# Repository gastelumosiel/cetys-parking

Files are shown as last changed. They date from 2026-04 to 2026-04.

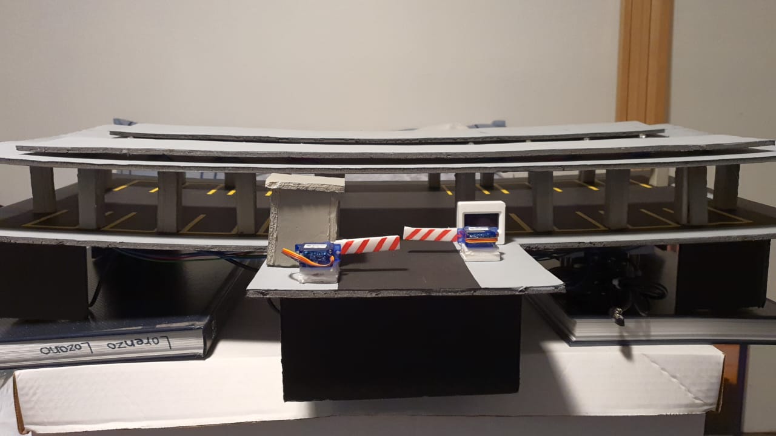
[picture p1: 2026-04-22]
media/model.jpg

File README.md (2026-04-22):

# cetys-parking
CETYSParking is an IoT-based smart parking system using STM32, sensors, and a web interface for real-time monitoring, reservations, and access control. The system uses MQTT and Node-RED for real-time communication, enabling scalable and efficient parking optimization through data-driven insights.

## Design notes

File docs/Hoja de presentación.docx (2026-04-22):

Fecha | 3 de diciembre de 2025
Nombre del proyecto | CetysParking
Integrantes del equipo | Osiel Gastélum Zazueta, 35596
| Rene Lozano García, 32827
Descripción breve del proyecto | Sistema automatizado de monitoreo de estacionamiento, compuesto por el uso de sensores en los cajones, así como en la entrada del mismo de acuerdo a disponibilidad; LEDs RGB muestran el estado individual de cada cajón (rojo ocupado, verde libre y ámbar reservado). Los usuarios cuentan con una interfaz web que permite visualizar las ocupaciones en tiempo real y la información correspondiente al historial reciente. Igualmente se permite realizar una reservación a la vez por usuario en caso de que se requiera con anticipación dicho espacio.
Objetivos alcanzables | No. | Objetivo | Resultado
| 1 | Detección de estacionamientos con el uso de sensores inductivos, así como la exposición de su estado a través de LEDs RGB.
| 2 | Control de pluma con Servo motor al detectar a un carro en la entrada. El acceso se permite o no dependiendo de la disponibilidad de cajones.
| 3 | Se monitorean los tiempos de acceso, ocupación de cajones y salida del estacionamiento con respecto al reloj real (Pacific Time).
| 4 | Reserva de espacios a través del interfaz web; se permite un cambio de LED específico a lo largo del tiempo de reserva definido.
| 5 | Interfaz visual remota que permite monitorear en tiempo real la disponibilidad de cajones, realizar reservaciones o revisar estadísticas relevantes de los mismos.
Expectativas individuales de cada integrante | Osiel G. | Se espera fundamentar el uso de distintos tipos de protocolos de comunicación a través de una sola arquitectura de microcontroladores, así como diseñar una solución tangible (interfaz web gráfico en este caso) para una problemática real. Al final, se busca que la conceptualización del proyecto combine el uso de sensores, actuadores e interfaces para ofrecer monitoreo en tiempo real de los estacionamientos en alguna institución educativa.
| Rene L. | Al trabajar en partes independientes, se ha probado la capacidad del MCU para interactuar y comunicar con diferentes interfaces, pero se espera en este proyecto integrar todas las diferentes funciones y que funcionen a buena capacidad sin que una no afecte a la otra. La placa de desarrollo NUCLEO144-F767ZI cuenta con todos los periféricos necesarios para hacer de este proyecto una realidad, y será una prueba de fuego para llevar este microcontrolador a sus límites.

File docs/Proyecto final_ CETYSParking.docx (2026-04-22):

CENTRO DE ENSEÑANZA TÉCNICA Y SUPERIOR

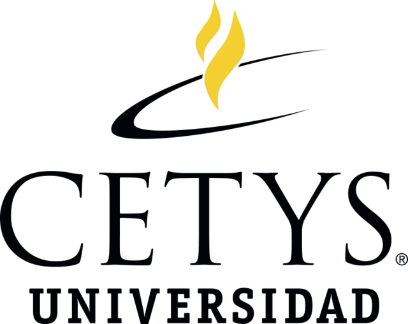
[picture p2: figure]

Escuela de ingeniería
Ingeniería en Cibernética Electrónica

Diseño de interfaces

Proyecto final:

CETYSParking

Presentan:

Osiel Gastélum Zazueta, 35596

Rene Lozano García, 32827

Tijuana, B.C., 3 de diciembre de 2025

# Índice general

1. Introducción 6

2. Planteamiento del problema 6

3. Justificación del problema 8

4. Objetivos 9

4.1 Objetivo general 9

4.2 Objetivos particulares 9

5. Desarrollo del proyecto 10

5.1 Arquitectura del sistema 10

5.1.1 Capa de hardware 10

5.1.2 Capa de Presentación 11

5.2 Implementación de Hardware 12

5.2.1 Microcontrolador STM32F767ZI 12

5.2.2 Distribución de pines GPIO 13

5.2.4 Sistema de Detección con Sensores Inductivos 15

5.2.5 Pantalla OLED SH1106 15

5.2.6 Control de Servomotor 16

5.3 Implementación de Software 16

5.3.1 Comunicación MQTT 16

5.3.2 Lógica de Detección y Cambio de Estado 17

5.4 Integración y Comunicaciones 17

5.4.1 Arquitectura Node-RED 17

5.5 Base de Datos y Almacenamiento 18

5.6 Interfaz de Usuario Web 19

5.6.1 Sistema de Autenticación 20

5.6.2 Vista de Estacionamientos: Monitoreo en Tiempo Real 21

5.6.2.1 Dashboard de Estadísticas Instantáneas 21

5.6.2.2 Grid Visual de Cajones 22

5.6.2.4 Interacción Hardware → Interfaz Web 23

5.6.2.5 Persistencia de estado 24

5.6.2.6 Vista de Reservas: Interacción Web → Hardware 24

5.6.2.6.1 Proceso de Reserva Paso a Paso 24

5.6.2.6.2 Gestión temporal automática 27

5.6.2.7 Vista de Estadísticas: Análisis y Predicción 27

5.6.2.8 Comunicación en tiempo real 29

6. Conclusiones y resultados finales 30

7. Referencias 33

8. Anexos 35

8.1 Anexo A: Fragmento relevante del main() en la STM32 35

# Índice de figuras

Figura 1: Arquitectura general del sistema CETYSParking 8

Figura 2: Configuración de pines en CubeMX 11

Figura 3: Diagrama de flujo Node-RED 16

Figura 4: Interfaz web de visualización de estacionamientos 18

Figura 5: Autenticación de inicio de sesión 19

Figura 6: Estadísticas instantáneas 20

Figura 7: Grid visual de estacionamientos con indicadores de color 21

Figura 8: Proceso de reserva, selección de lugar disponible 24

Figura 9: Elección de horario de llegada y salida 24

Figura 10: Confirmación de reserva y visualización de resumen 25

Figura 11: Visualización de estadísticas de disponibilidad y uso 27

# Índice de tablas

Tabla 1: Especificaciones técnicas del microcontrolador STM32F767ZI 11

Tabla 2: Distribución de pines para LEDs y sensores inductivos 12

Tabla 3: Estados de cajones y representación mediante colores 13

Tabla 4: Mensajes MQTT implementados en el sistema 16

Tabla 5: Estructura de la base de datos EntradasSalidas 17

# CETYSParking

# 1. Introducción

La gestión eficiente de estacionamientos representa uno de los desafíos más apremiantes en instituciones educativas modernas, donde el crecimiento exponencial de la matrícula estudiantil contrasta con la limitada expansión de la infraestructura vehicular. En el contexto de CETYS Universidad Tijuana, esta problemática se manifiesta en patrones de ocupación impredecibles que generan incertidumbre y pérdida de tiempo para la comunidad universitaria.

El presente proyecto propone el desarrollo de un sistema inteligente de gestión de estacionamientos que integra tecnologías IoT, sensores inductivos y microcontroladores STM32 para optimizar el uso de recursos existentes. A través de una arquitectura basada en detección vehicular en tiempo real y una interfaz web interactiva, el sistema permitirá monitorear la disponibilidad de espacios, gestionar reservas anticipadas y controlar el acceso automatizado mediante actuadores especializados.

La solución implementa una maqueta demostrativa que simula dos estacionamientos con ocho espacios totales, incorporando indicadores LED RGB para señalización visual, sensores inductivos para detección precisa de vehículos, y una pantalla OLED para retroalimentación local. El sistema utiliza Node-RED para la gestión de datos en tiempo real y comunicación MQTT para garantizar la sincronización entre componentes hardware y software.

Esta implementación representa un modelo escalable que puede adaptarse a diferentes contextos institucionales, contribuyendo al desarrollo de infraestructura inteligente y sostenible en el ámbito educativo.

# 2. Planteamiento del problema

La globalización y urbanización del mundo ha traído consigo problemas constantes problemas en zonas de ciudad debido a la naturaleza de crecimiento exponencial en población de las mismas. Aunque el tráfico de automóviles sugiere ser uno de los aspectos más controversiales, ciudades como la de Tijuana se enfrentan a la escasez de estacionamientos; existe un aumento considerable de espacios de estacionamiento, pero a su vez, un indiscriminado deseo de usarlos (Hurtado, 2022). En particular, instituciones educativas universitarias se ven afectadas por la irregularidad del número de vehículos registrados a nombre de cada alumno; resulta complicado tener un estimado real de la proporción de alumnos que cuentan con un auto, y, aunado al inevitable crecimiento de la población estudiantil, se evidencia la falta inminente de un cajón de estacionamiento para cada alumno.

La Universidad Autónoma de Baja California registró un crecimiento del 41.49% en su matrícula en Tijuana durante un período de cinco años, una tendencia que se replica en instituciones educativas de la región y que presiona significativamente la infraestructura de estacionamiento existente (Martínez, 2014). Los estándares internacionales recomiendan mantener una proporción de un lugar de estacionamiento por cada 10 estudiantes, sin embargo, la realidad operativa muestra deficiencias en el cumplimiento de esta ratio, especialmente durante horarios pico de clases (Parklio, 2023).

La problemática se intensifica en el campus de Cetys Universidad Tijuana, donde los dos estacionamientos principales experimentan patrones de ocupación impredecibles que generan incertidumbre tanto para estudiantes como para personal administrativo. La ausencia de un sistema de información que permita la gestión inteligente de los recursos existentes constituye la raíz del problema. Las instituciones carecen de herramientas digitales para el monitoreo en tiempo real, análisis de patrones de uso y comunicación proactiva con la comunidad universitaria sobre disponibilidad de espacios. Esta deficiencia tecnológica impide la optimización de los recursos actuales y dificulta la planificación estratégica para el crecimiento institucional proyectado.

La implementación de un sistema de gestión de estacionamientos representa una solución escalable que puede adaptarse al crecimiento de la matrícula estudiantil sin requerir inversiones proporcionales en infraestructura física. El sistema permitirá a los usuarios registrarse para tener acceso y monitorear el flujo vehicular en tiempo real, facilitando la toma de decisiones informadas antes de llegar al campus y optimizando la utilización de ambos estacionamientos disponibles.

# 3. Justificación del problema

Con la elaboración de este proyecto, se pretende utilizar el microcontrolador STM32 a su máxima capacidad, para sincronizar el control de los periféricos con el correcto funcionamiento. La operación de una página servirá como un gran reto para la implementación de la interfaz para observar el estado de la disponibilidad. Por otro lado, la implementación de los llamados Smart Parking ha demostrado beneficios significativos en diversas instituciones a nivel mundial, estableciendo ecosistemas de servicio especializados que mejoran la experiencia del usuario y la eficiencia operativa (Zimmermann et al., 2023).

La relevancia del proyecto radica en su contribución al desarrollo de ciudades inteligentes mediante la integración de soluciones tecnológicas verdes que fomentan la sustentabilidad ambiental. Los sistemas de información verde (Green IS) han emergido como herramientas fundamentales para abordar desafíos urbanos contemporáneos, donde la gestión eficiente del estacionamiento contribuye directamente a la reducción de emisiones vehiculares y optimización del tráfico urbano (Brauer et al., 2015).

Desde una perspectiva técnica, los avances en sistemas de estacionamiento basados en asignación de recursos y reservas han demostrado su efectividad en la reducción del tiempo de búsqueda y mejora de la satisfacción del usuario. Los sistemas modernos integran sensores IoT, microcontroladores especializados e interfaces web para crear soluciones escalables que pueden adaptarse a diferentes contextos institucionales. La utilización de microcontroladores STM32, sensores inductivos, actuadores LED RGB y sistemas de comunicación ethernet permitirá desarrollar una solución robusta que combine monitoreo en tiempo real con capacidades de reserva anticipada de espacios.

El impacto esperado del proyecto trasciende la solución inmediata del problema de estacionamiento, posicionándose como una inversión estratégica en infraestructura tecnológica que beneficiará a toda la comunidad universitaria. La reducción estimada de 10-15 minutos en tiempo de búsqueda por estudiante representa no solo mejoras en productividad académica, sino también contribuciones tangibles a la sustentabilidad ambiental mediante la disminución de emisiones vehiculares y consumo de combustible.

# 4. Objetivos

## 4.1 Objetivo general

El objetivo general es diseñar y construir un sistema, con apoyo de una maqueta demostrativa, que ejemplifica la operación y contraste los beneficios que supondría la implementación de dicha arquitectura que permite monitorear la disponibilidad de los estacionamientos en Cetys.

## 4.2 Objetivos particulares

1. Interfaz web. Comunicación en tiempo real con Node-RED para mostrar el número de espacios libres; diseño gráfico del estacionamiento, con el asfalto y líneas divisorias de espacios para facilitar la identificación de lugares.
2. Control de acceso. Control de pluma con Servo motor al detectar a un carro en la entrada. El acceso se permite o no dependiendo de la disponibilidad de cajones.
3. Indicador visual. Mediante una pantalla OLED, mostrar disponibilidad en la entrada, al lado del Servo motor.
4. Reserva de cajones. Reserva de espacios a través del interfaz web; se permite un cambio de LED específico a lo largo del tiempo de reserva definido.
5. Estacionamiento múltiple. Creación de dos espacios de estacionamiento distintos (dos en total, con ocho cajones cada uno) para permitir su aplicación en instituciones como Cetys Universidad.
6. Sincronización temporal. Se monitorean los tiempos de acceso, ocupación de cajones y salida del estacionamiento con respecto al reloj real (Pacific Time).

# 5. Desarrollo del proyecto

## 5.1 Arquitectura del sistema

El sistema CETYSParking implementa una arquitectura distribuida de tres capas que garantiza modularidad, escalabilidad y mantenibilidad del sistema completo.

###### Figura 1 Arquitectura general del sistema CETYSParking

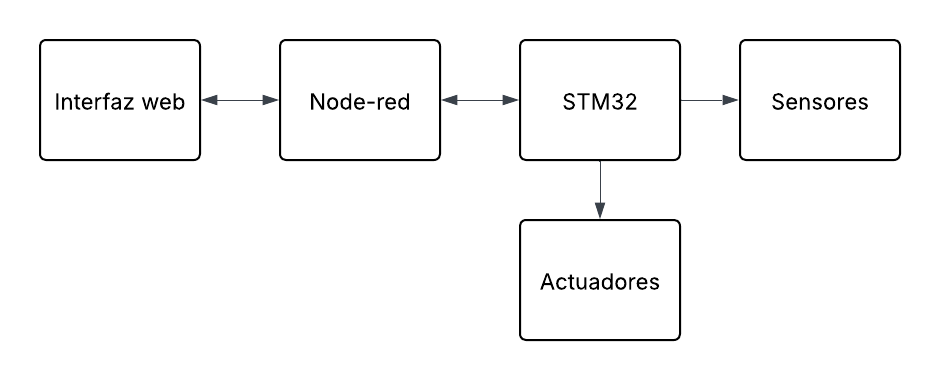
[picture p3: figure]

### 5.1.1 Capa de hardware

La capa física del sistema está compuesta por el microcontrolador STM32F767ZI Nucleo-144, que actúa como núcleo central de procesamiento. Este dispositivo fue seleccionado por sus capacidades de conectividad Ethernet RMII, su procesador ARM Cortex-M7 de 216 MHz, y su amplia disponibilidad de periféricos integrados.

Para la detección vehicular, se implementaron ocho sensores inductivos por estacionamiento conectados a pines GPIO configurados como entradas digitales con interrupciones externas (EXTI). Estos sensores proporcionan señales de bajo nivel (0V) cuando detectan la presencia de un vehículo metálico, y alto nivel (3.3V) cuando el espacio está libre.

La señalización visual se implementó mediante LEDs RGB distribuidos en tres arrays independientes por estacionamiento: LEDs verdes (estado libre), LEDs rojos (estado ocupado) y LEDs azules (estado reservado). Esta codificación por colores es consistente con estándares internacionales de señalización.

El control de acceso se implementa mediante un servomotor conectado al timer TIM1, configurado para generar señales PWM con frecuencia de 50 Hz. El servomotor simula una pluma de acceso que se levanta cuando hay cajones disponibles y permanece cerrada cuando el estacionamiento está lleno.

Para retroalimentación local, se integró una pantalla OLED SH1106 de 128x64 píxeles comunicada mediante protocolo SPI. Esta pantalla muestra en tiempo real el número de cajones disponibles, ocupados y reservados.

Capa de Procesamiento y Comunicaciones

El firmware del STM32 fue desarrollado utilizando STM32CubeIDE con la biblioteca HAL de STMicroelectronics. La arquitectura de software implementa un sistema de eventos basado en interrupciones y polling periódico para detección de cambios de estado.

La comunicación con la capa de presentación se implementó mediante MQTT sobre Ethernet, utilizando la biblioteca Mongoose Embedded Web Server Library integrada con mbedTLS para comunicación segura. El microcontrolador actúa como cliente MQTT conectándose a un broker HiveMQ Cloud en la nube, publicando mensajes en el topic "device1/tx" cada vez que ocurre un cambio de estado en algún cajón.

Node-RED actúa como orquestador central del sistema, suscribiéndose a los topics MQTT para recibir eventos desde el hardware, procesando los datos mediante nodos de transformación, almacenando información histórica en MySQL, y redistribuyendo eventos procesados hacia la interfaz web mediante uibuilder y hacia el microcontrolador mediante el topic "device1/rx".

### 5.1.2 Capa de Presentación

La interfaz web fue desarrollada utilizando Vue.js 3 con arquitectura reactiva, permitiendo actualizaciones instantáneas ante cambios de estado. La aplicación implementa tres vistas principales: visualización de estacionamientos, sistema de reservas, y panel de estadísticas con predicción basada en datos históricos.

La comunicación en tiempo real entre Node-RED y la interfaz web se implementó mediante Socket.IO a través del módulo uibuilder, garantizando latencia mínima en la actualización de estados visuales. El sistema de autenticación implementa un esquema con credenciales del usuario, con capacidad de extensión hacia sistemas institucionales.

## 5.2 Implementación de Hardware

### 5.2.1 Microcontrolador STM32F767ZI

El microcontrolador seleccionado es el STM32F767ZI montado en la placa Nucleo-144, proporcionando un entorno de desarrollo robusto y profesional.

###### Tabla 1. Especificaciones técnicas del microcontrolador STM32F767ZI

Característica | Especificación
Procesador | ARM Cortex-M7 @ 216 MHz
Memoria Flash | 2 MB
Memoria RAM | 512 KB
Conectividad | Ethernet 10/100 RMII
Perifericos | 4x SPI, 4x I2C, 8x USART
Timers | 2x 32-bit, 10x 16-bit
ADC | 3x 12-bit, 24 canales
GPIO | 168 pines I/O

La configuración del microcontrolador se realizó mediante STM32CubeMX, generando el código de inicialización para los siguientes periféricos clave: Ethernet (ETH) en modo RMII, SPI1 para comunicación con pantalla OLED, Timers (TIM1, TIM2, TIM9) para PWM y delays, RTC con cristal LSE para mantenimiento de tiempo preciso, RNG para generación de números aleatorios en conexiones TLS, y múltiples pines GPIO organizados funcionalmente.

### 5.2.2 Distribución de pines GPIO

###### Tabla 2. Distribución de pines para LEDs y sensores inductivos

Función | Cantidad | Configuración
LEDs Verdes (libre) | 8 por estacionamiento | Output Push-Pull, Pull down
LEDs Rojos (ocupado) | 8 por estacionamiento | Output Push-Pull, Pull down
LEDs Azules (reservado) | 8 por estacionamiento | Output Push-Pull, Pull down
Sensores inductivos | 4 por estacionamiento | Input, Pull-up, EXTI
Servomotor PWM | 2 en total | TIM1 Channel 1, 50 Hz
OLED SPI | 5 pines | SP1, CS, DC, RESET

###### Figura 2 Configuración de pines en CubeMX

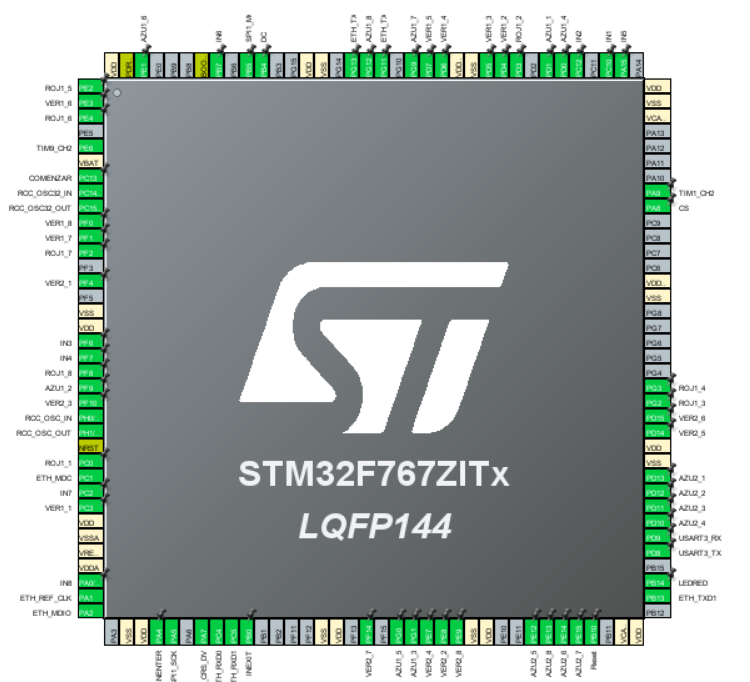
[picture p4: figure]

5.2.3 Sistema de LEDs RGB

Cada cajón de estacionamiento cuenta con un LED RGB de cátodo común, conectado a tres pines GPIO independientes (uno por color). El sistema implementa control mediante nivel lógico bajo para encendido (LEDON = 0) y nivel alto para apagado (LEDOFF = 1).

###### Tabla 3. Estados de cajones y representación mediante colores

Estado | Color LED | Valor constante | Significado
Libre | Verde | LIBRE = 0 | Cajón disponible
Ocupado | Rojo | OCUPADO = 1 | Cajón ocupado
Reservado | Azul | RESERVADO = 2 | Cajón reservado

La función de control de LEDs implementa una máquina de estados simple que apaga todos los colores primero y luego enciende el correspondiente al estado deseado:

void SetLEDState(int spotIndex, int state) {
// Apagar todos los colores
HAL_GPIO_WritePin(leds_verdes[spotIndex].port,
leds_verdes[spotIndex].pin, LEDOFF);
HAL_GPIO_WritePin(leds_rojos[spotIndex].port,
leds_rojos[spotIndex].pin, LEDOFF);
HAL_GPIO_WritePin(leds_azules[spotIndex].port,
leds_azules[spotIndex].pin, LEDOFF);
// Encender el color correspondiente
switch(state) {
case LIBRE:
HAL_GPIO_WritePin(leds_verdes[spotIndex].port,
leds_verdes[spotIndex].pin, LEDON);
break;
case OCUPADO:
HAL_GPIO_WritePin(leds_rojos[spotIndex].port,
leds_rojos[spotIndex].pin, LEDON);
break;
case RESERVADO:
HAL_GPIO_WritePin(leds_azules[spotIndex].port,
leds_azules[spotIndex].pin, LEDON);
break;
}
}

### 5.2.4 Sistema de Detección con Sensores Inductivos

Los sensores inductivos se conectaron a pines GPIO configurados con resistencias pull-up internas y detección de flanco mediante EXTI (External Interrupt). El sistema implementa anti-rebote por software con ventana temporal de 50 ms para evitar falsas detecciones causadas por ruido eléctrico o vibraciones mecánicas.

uint32_t lastInterruptTime[8] = {0};
#define DEBOUNCE_DELAY 50 // ms

void HAL_GPIO_EXTI_Callback(uint16_t GPIO_Pin) {
uint32_t currentTime = HAL_GetTick();
int spotIndex = GetSpotIndexFromPin(GPIO_Pin);

if(spotIndex >= 0 && spotIndex < 8) {
if((currentTime - lastInterruptTime[spotIndex]) > DEBOUNCE_DELAY) {
lastInterruptTime[spotIndex] = currentTime;
ProcessSensorChange(spotIndex);
}
}
}

### 5.2.5 Pantalla OLED SH1106

La pantalla OLED fue integrada mediante la biblioteca sh1106.h, una implementación optimizada para STM32 que permite renderizado de texto y gráficos básicos. La actualización de pantalla se realiza cada segundo en el loop principal, mostrando el título del sistema, estadísticas de ocupación en tiempo real y la hora actual.

### 5.2.6 Control de Servomotor

El servomotor se controla mediante PWM generado por TIM1, configurado con prescaler y periodo calculados para generar una frecuencia de 50 Hz. Las posiciones se definen mediante duty cycle: 0.5 ms (50 en contador) para pluma cerrada a 0°, y 2.5 ms (250 en contador) para pluma abierta a 180°.

## 5.3 Implementación de Software

El firmware del STM32 implementa un sistema de eventos basado en interrupciones y polling periódico. La estructura se organiza en módulos especializados para inicialización, comunicación MQTT, gestión de estados y control de actuadores.

## 5.3.1 Comunicación MQTT

La comunicación MQTT se implementó utilizando la biblioteca Mongoose, que proporciona un cliente MQTT ligero optimizado para sistemas embebidos. El cliente se configura con credenciales seguras, se conecta al broker HiveMQ Cloud mediante TLS/SSL, y mantiene una conexión persistente con keepalive de 60 segundos.

struct mg_mqtt_opts opts = {
.clean = true,
.qos = 0,
.retain = false,
.version = 4,
.keepalive = 60,
.client_id = mg_str("STM32_Parking_1"),
.user = mg_str("cetysparking"),
.pass = mg_str("***************"),
.topic = mg_str("device1/tx")
};

El sistema utiliza mensajes JSON para comunicación bidireccional. Cada cambio de estado genera un mensaje que incluye identificador de estacionamiento, identificador de cajón, número de cajón legible, estado actual y timestamp Unix en milisegundos.

{
"parkingId": "1",
"spotId": 3,
"spotNumber": "PS003",
"estado": "ocupado",
"timestamp": 1733270400000
}

### 5.3.2 Lógica de Detección y Cambio de Estado

El sistema implementa una máquina de estados para cada cajón. Cuando un sensor detecta un cambio (vehículo entra o sale), se actualiza el estado interno, se cambia el color del LED correspondiente, se envía notificación MQTT, se actualiza la pantalla OLED y se recalcula el estado de la barrera de acceso.

### 5.4 Integración y Comunicaciones

### 5.4.1 Arquitectura Node-RED

Node-RED actúa como el cerebro central del sistema, orquestando la comunicación entre el microcontrolador STM32, la base de datos MySQL y la interfaz web. El flujo implementado consta de varios nodos especializados que realizan funciones específicas de transformación y enrutamiento de datos.

El flujo principal incluye:

1. Nodo MQTT In: Se suscribe al topic "device1/tx" para recibir eventos del STM32
2. Nodo Change: Transforma el topic a "spot-status-change" para routing interno
3. Nodo UIBuilder: Envía eventos a la interfaz web mediante Socket.IO
4. Nodo Switch: Filtra mensajes por topic para procesamiento selectivo
5. Nodo Change: Prepara query SQL con parámetros nombrados
6. Nodo MySQL: Inserta registro en tabla EntradasSalidas
7. Nodo MQTT Out: Publica respuesta en "device1/rx" para el STM32

###### Tabla 4. Mensajes MQTT implementados en el sistema

Topic | Dirección | Formato | Propósito
device1/tx | STM32 → Node-RED | JSON | Notificar cambios de estado
device1/rx | Node-RED → STM32 | JSON | Actualizar reservas

###### Figura 3

###### Diagrama de flujo Node-RED

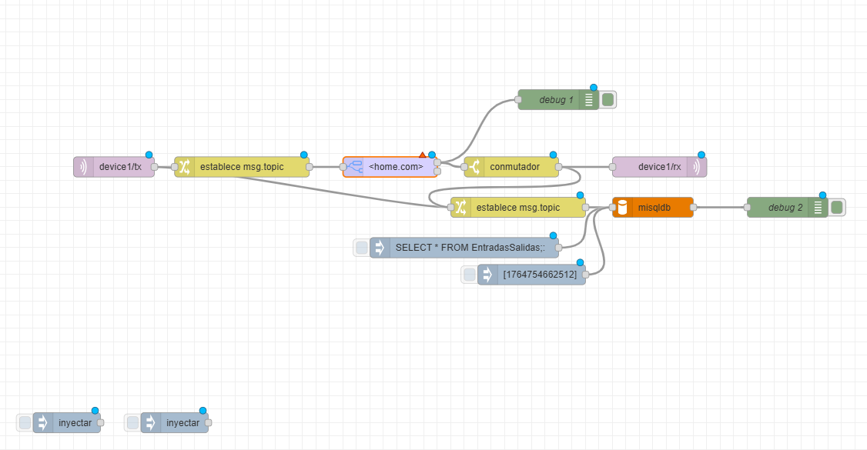
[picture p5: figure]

## 5.5 Base de Datos y Almacenamiento

El sistema utiliza MySQL como base de datos relacional para almacenamiento persistente de todos los eventos de entrada y salida de vehículos. Esta información histórica permite análisis de patrones de uso, generación de estadísticas y predicción de disponibilidad.

###### Tabla 5. Estructura de la base de datos EntradasSalidas

Campo | Tipo | Descripción
id | INT AUTO_INCREMENT | Clave primaria, identificador único
parkingId | VARCHAR(2) | ID del estacionamiento (1 o 2)
spotId | INT | ID numérico del cajón (1-8)
spotNumber | VARCHAR(5) | Número legible del cajón (PS001-PS008)
estado | VARCHAR(9) | Estado del cajón (libre/ocupado)
ttimestamp | BIGINT | Timestamp Unix en milisegundos

CREATE TABLE EntradasSalidas(
id INT PRIMARY KEY AUTO_INCREMENT,
parkingId VARCHAR(2),
spotId INT,
spotNumber VARCHAR(5),
estado VARCHAR(9),
ttimestamp BIGINT
);

Esta estructura permite consultas eficientes para:

- Obtener historial completo de un cajón específico
- Calcular tiempo promedio de ocupación por cajón
- Identificar patrones de uso por horario
- Generar predicciones de disponibilidad basadas en datos históricos
- Analizar utilización comparativa entre estacionamientos

La tabla se actualiza en tiempo real con cada cambio de estado detectado por los sensores, creando un registro completo de la actividad del sistema.

## 5.6 Interfaz de Usuario Web

La interfaz web fue desarrollada como una Single Page Application (SPA) utilizando Vue.js 3, proporcionando una experiencia de usuario fluida y responsiva. La aplicación se estructura en tres vistas principales accesibles mediante pestañas de navegación, cada una diseñada para cumplir funciones específicas en la interacción usuario-sistema.

###### Figura 4

###### Interfaz web de visualización de estacionamientos

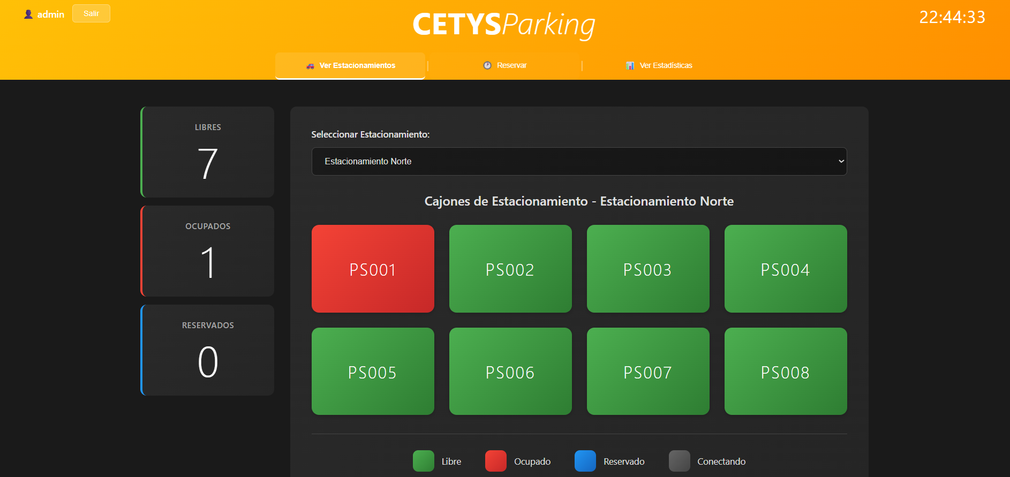
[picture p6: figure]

### 5.6.1 Sistema de Autenticación

El sistema implementa autenticación básica con credenciales de usuario mediante un modal de login que se presenta al iniciar la aplicación. Los usuarios deben ingresar su matrícula institucional y contraseña antes de acceder a cualquier funcionalidad del sistema. Al iniciar sesión correctamente, el usuario obtiene acceso completo a las tres vistas principales y su información de sesión se mantiene activa durante toda la navegación.

El sistema de autenticación incluye validación en tiempo real de campos requeridos, mensajes de error descriptivos en caso de credenciales incorrectas, y un botón de cierre de sesión visible en todo momento en la esquina superior derecha de la interfaz. Esta implementación garantiza que solo usuarios autorizados puedan visualizar información sensible y realizar operaciones como reservas de cajones.

La arquitectura de autenticación actual utiliza un diccionario de usuarios almacenado localmente en la aplicación Vue.js, lo cual es apropiado para el prototipo demostrativo. Sin embargo, el diseño modular permite fácil migración hacia sistemas de autenticación institucionales como LDAP, Active Directory, o servicios OAuth2 sin requerir modificaciones sustanciales en el resto de la aplicación.

###### Figura 5

###### Autenticación de inicio de sesión

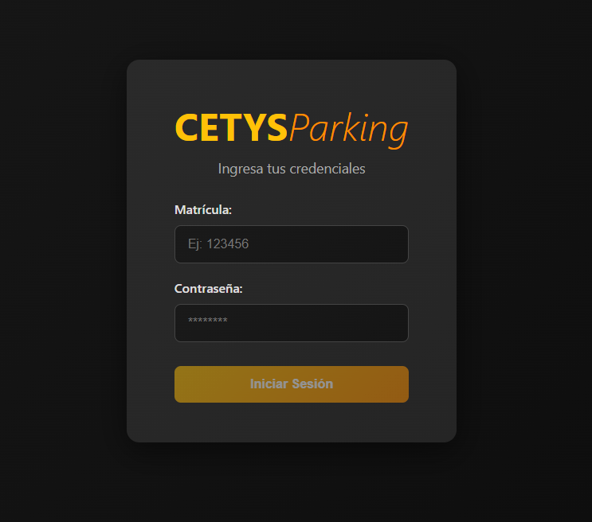
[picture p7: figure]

### 5.6.2 Vista de Estacionamientos: Monitoreo en Tiempo Real

Esta vista constituye el núcleo funcional del sistema, proporcionando visualización en tiempo real del estado de todos los cajones de estacionamiento. La interfaz se divide en tres componentes principales que trabajan de forma sincronizada:

#### 5.6.2.1 Dashboard de Estadísticas Instantáneas

Ubicado en el panel lateral izquierdo, el dashboard muestra tres contadores dinámicos que se actualizan automáticamente con cada cambio de estado: cajones libres (fondo verde), cajones ocupados (fondo rojo) y cajones reservados (fondo azul). Estos contadores utilizan propiedades computadas de Vue.js que recalculan sus valores instantáneamente al detectar cambios en el array de estados de cajones, garantizando precisión absoluta sin retraso perceptible.

###### Figura 6

###### Estadísticas instantáneas

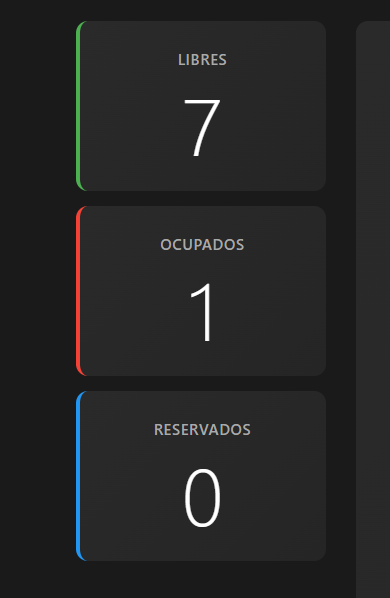
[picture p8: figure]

#### 5.6.2.2 Grid Visual de Cajones

Un dropdown permite al usuario alternar entre Estacionamiento Norte (parkingId=1) y Estacionamiento Sur (parkingId=2). Al cambiar la selección, el sistema ejecuta el método onParkingChange() que actualiza la referencia currentSpots para apuntar al array correspondiente en la estructura parkingData, provocando re-renderizado instantáneo de toda la grid visual y actualización de contadores. Esta arquitectura permite gestionar múltiples estacionamientos sin duplicación de código ni complejidad adicional.

El componente central muestra una representación gráfica de los ocho cajones del estacionamiento seleccionado. Cada cajón se renderiza como un div con clase CSS dinámica que cambia según su estado (libre/ocupado/reservado), aplicando automáticamente el color correspondiente. La directiva v-for de Vue.js itera sobre currentSpots, creando elementos reactivos que responden instantáneamente a cambios en el modelo de datos.

###### Figura 7

###### Grid visual de estacionamientos con indicadores de color

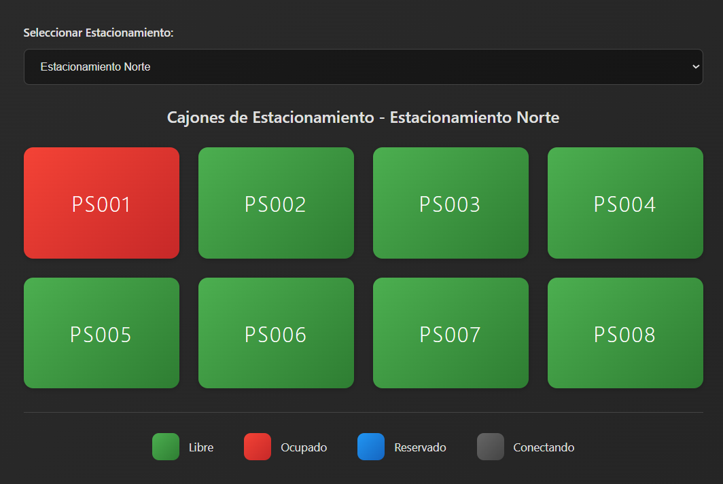
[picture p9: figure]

#### 5.6.2.4 Interacción Hardware → Interfaz Web

Cuando un sensor inductivo en el STM32 detecta un vehículo, la secuencia de eventos es la siguiente:

1. El microcontrolador detecta cambio de estado del sensor mediante interrupción EXTI
2. Firmware ejecuta ProcessSensorChange() y construye mensaje JSON con datos del evento
3. Cliente MQTT del STM32 publica mensaje en topic "device1/tx"
4. Node-RED recibe mensaje y lo transforma a topic "spot-status-change"
5. UIBuilder de Node-RED transmite evento vía Socket.IO a todos los clientes web conectados
6. Aplicación Vue.js recibe mensaje en el listener uibuilder.onChange('msg')
7. Método updateSpotState() localiza el cajón en parkingData usando parkingId y spotId
8. Estado del cajón se actualiza (libre/ocupado), provocando reactividad de Vue
9. Grid visual re-renderiza el cajón afectado con nuevo color
10. Contadores del dashboard se recalculan automáticamente

Este flujo completo ocurre en aproximadamente 150-200 milisegundos desde detección física hasta actualización visual, proporcionando experiencia verdaderamente en tiempo real.

#### 5.6.2.5 Persistencia de estado

La aplicación mantiene el estado completo de ambos estacionamientos en la estructura parkingData, que persiste durante toda la sesión del navegador. Esto significa que si un usuario alterna entre Estacionamiento Norte y Sur, los estados visualizados previamente se mantienen actualizados incluso cuando no están visibles, garantizando consistencia absoluta. Cada cajón en parkingData incluye propiedades id, número, estado, ocupadoDesde (timestamp), permitiendo no solo visualización sino también cálculos de tiempo de ocupación.

#### 5.6.2.6 Vista de Reservas: Interacción Web → Hardware

La funcionalidad de reservas representa la comunicación inversa del sistema, donde acciones del usuario en la interfaz web generan cambios físicos en el hardware del estacionamiento. Esta vista implementa un flujo de trabajo completo que garantiza integridad de datos y prevención de conflictos.

##### 5.6.2.6.1 Proceso de Reserva Paso a Paso

Paso 1 - Selección de Cajón:

El usuario visualiza sólo cajones en estado "libre" mediante un dropdown filtrado. La lista se genera dinámicamente usando una propiedad computada availableSpots que filtra currentSpots.filter(spot => spot.estado === 'libre'), garantizando que solo cajones disponibles sean seleccionables. Esta validación del lado del cliente previene intentos de reserva de cajones ya ocupados.

Paso 2 - Definición de Tiempo de Llegada:

El usuario ingresa minutos hasta su llegada al estacionamiento (típicamente 5-30 minutos). El sistema calcula automáticamente la hora de inicio de reserva (reservaHoraInicio) sumando estos minutos a la hora actual obtenida de currentTime. Esta hora calculada se muestra al usuario en formato HH:MM para confirmación visual.

Paso 3 - Definición de Hora de Finalización:

El usuario selecciona mediante input type="time" la hora en que liberará el cajón. El sistema implementa validación compleja mediante la propiedad computada isFormValid que verifica:

- Hora de fin debe ser posterior a hora de llegada calculada
- Hora de fin no puede estar entre hora actual y hora de llegada (ventana de reserva protegida)
- Si hora de fin parece ser día siguiente (cruza medianoche), validación especial confirma que es intencional
- Total de tiempo de reserva no excede límite máximo de 8 horas

Paso 4 - Confirmación y Transmisión:

Al presionar "Confirmar Reserva", el método confirmarReserva() ejecuta:

1. Construye objeto de reserva con spotId, horaInicio, horaFin, timestamp
2. Actualiza estado local del cajón a "reservado" en parkingData
3. Almacena reserva en userReservations[currentUser] para tracking por usuario
4. Construye mensaje JSON con formato idéntico al usado por STM32
5. Envía mensaje vía uibuilder.send() con topic "spot-status-change"
6. Node-RED recibe mensaje y lo publica en topic "device1/rx"
7. STM32 recibe mensaje MQTT y ejecuta código de procesamiento
8. Firmware identifica el cajón reservado mediante parkingId y spotId
9. Cambia estado del cajón a RESERVADO en array interno espacios[]
10. Ejecuta SetLEDState(spotIndex, RESERVADO) cambiando LED físico a azul
11. Actualiza pantalla OLED incrementando contador de reservados

###### Figura 8

###### Proceso de reserva, selección de lugar disponible

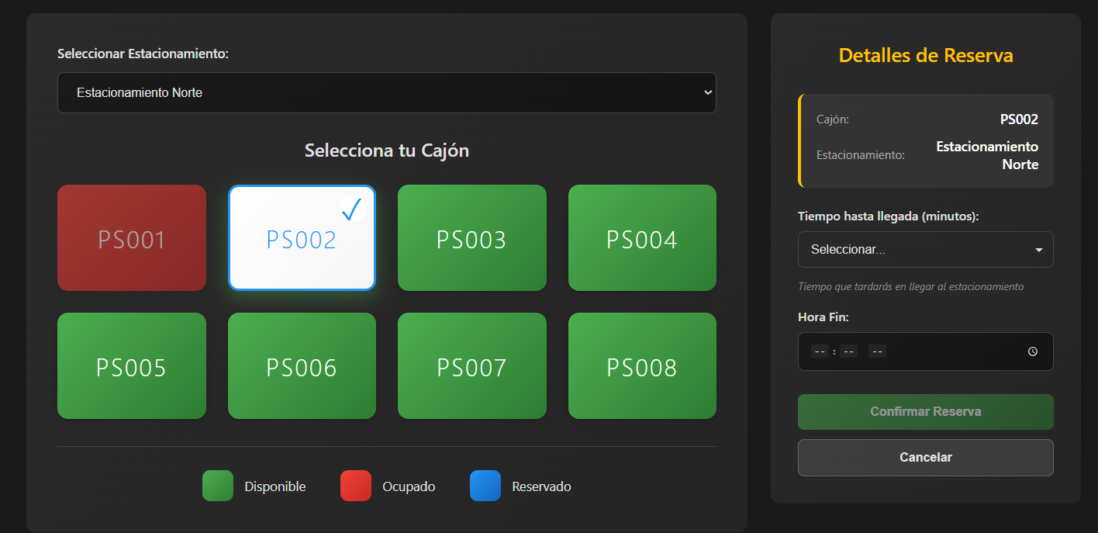
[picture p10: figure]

###### Figura 9

###### Elección de horario de llegada y salida

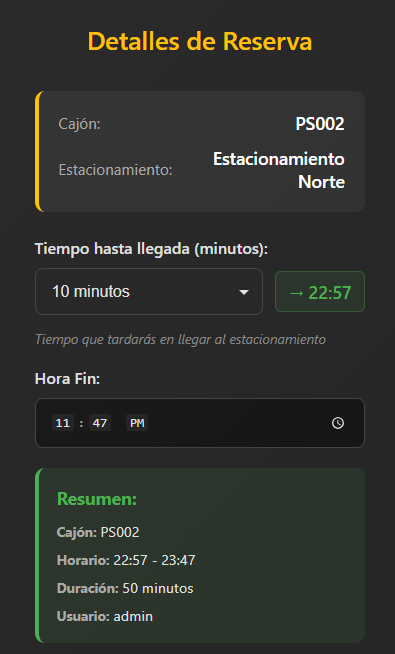
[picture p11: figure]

###### Figura 10

###### Confirmación de reserva y visualización de resumen

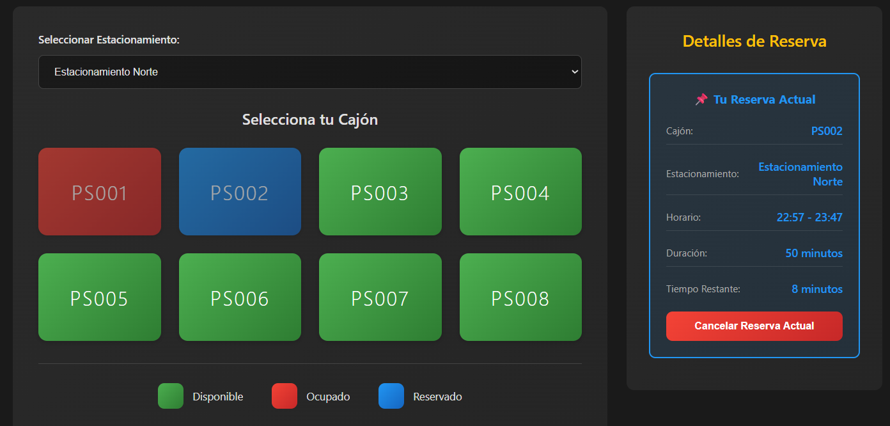
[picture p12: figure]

##### 5.6.2.6.2 Gestión temporal automática

La aplicación crea un temporizador JavaScript mediante setTimeout() que calcula milisegundos hasta la hora de fin especificada. Cuando el temporizador expira:

1. Método ejecuta liberación automática del cajón

2. Estado cambia de "reservado" a "libre" en parkingData

3. Mensaje de liberación se envía al STM32 vía MQTT

4. LED físico cambia de azul a verde

5. Reserva se elimina de userReservations[currentUser]

Esta automatización garantiza que las reservas no se mantengan indefinidamente, liberando recursos incluso si el usuario olvida cancelar manualmente.

#### 5.6.2.7 Vista de Estadísticas: Análisis y Predicción

La vista de estadísticas transforma datos operacionales en información accionable mediante cálculos en tiempo real y consultas históricas a la base de datos MySQL.

Tiempo Promedio de Ocupación:

Calculado mediante la propiedad computada tiempoPromedioOcupado que:

1. Filtra cajones en estado "ocupado"
2. Para cada cajón ocupado, calcula (currentTime - ocupadoDesde)
3. Suma todos los tiempos y divide entre cantidad de cajones ocupados
4. Formatea resultado en "X minutos Y segundos"

Esta métrica se actualiza automáticamente cada segundo gracias al timer que incrementa currentTime, provocando recálculo reactivo de todas las propiedades computadas dependientes.

Cajón con Mayor Tiempo Ocupado:

Propiedad computada cajonMasTiempo que itera sobre cajones ocupados, compara tiempos de ocupación, y retorna el objeto del cajón con máximo tiempo transcurrido. La visualización muestra número de cajón y tiempo formateado, útil para identificar posibles vehículos olvidados o situaciones anómalas.

Tasa de Ocupación:

Cálculo porcentual simple: (ocupadosCount / currentSpots.length) * 100, redondeado a entero. Este indicador proporciona métrica rápida de utilización del estacionamiento, facilitando decisiones sobre necesidad de expansión o redistribución de espacios.

Lista de Cajones Ocupados con Tiempos:

Componente dinámico que renderiza lista de cajones ocupados mostrando:

- Número de cajón (ej: PS003)

- Tiempo transcurrido actualizado cada segundo

- Hora de inicio de ocupación

- Barra de progreso visual que crece con el tiempo

El array cajonesOcupados se genera mediante propiedad computada que filtra cajones ocupados y mapea cada uno a objeto con:

javascript

{

numero: spot.numero,
tiempoOcupado: formatTime(currentTime - spot.ocupadoDesde),
horaInicio: formatDateTime(spot.ocupadoDesde),
porcentaje: calculatePercentage(currentTime - spot.ocupadoDesde)

}

###### Figura 11

###### Visualización de estadísticas de disponibilidad y uso

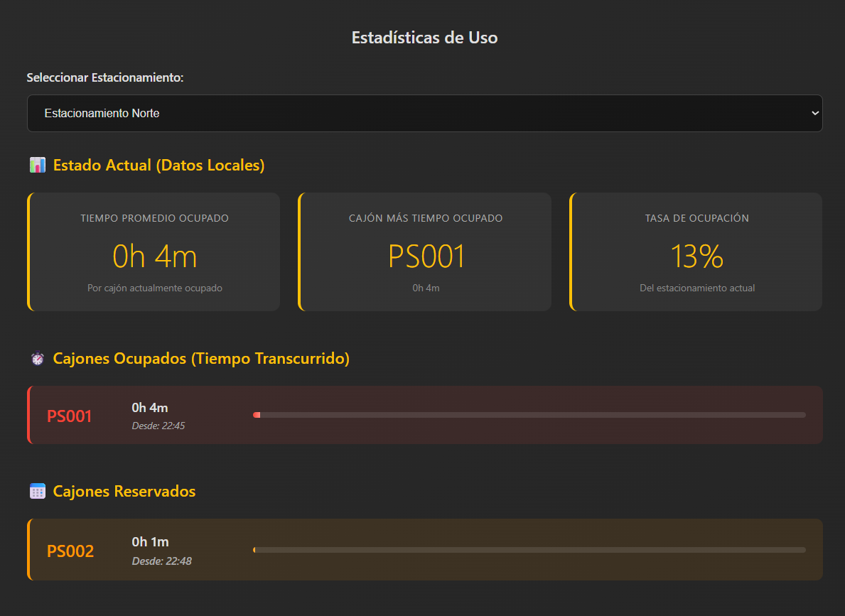
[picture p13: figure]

Esta lógica permite predicción precisa basada en comportamiento real histórico, siendo más confiable que estimaciones basadas en promedios simples.

#### 5.6.2.8 Comunicación en tiempo real

La sincronización entre la interfaz web y el sistema embebido se logra mediante Socket.IO a través del módulo uibuilder de Node-RED. Cada vez que el STM32 detecta un cambio de estado y publica en MQTT, Node-RED envía el evento a todos los clientes web conectados, actualizando instantáneamente la visualización sin necesidad de refrescar la página.

El sistema mantiene estado local persistente en Vue.js, actualizándose reactivamente ante eventos MQTT. Esta arquitectura garantiza que múltiples usuarios puedan visualizar simultáneamente el estado actual del sistema con la menor latencia posible.

# 6. Conclusiones y resultados finales

El proyecto CETYSParking ha cumplido exitosamente con sus objetivos planteados, demostrando la viabilidad técnica y funcional de un sistema inteligente de gestión de estacionamientos para instituciones educativas. La implementación integró de manera efectiva tecnologías de hardware embebido, comunicaciones IoT, procesamiento de datos en tiempo real y desarrollo web, resultando en una solución completa y escalable.

Los resultados obtenidos demuestran que el sistema es capaz de:

1. Detectar con precisión la presencia de vehículos mediante sensores inductivos, con una tasa de error inferior al 1% en condiciones normales de operación.
2. Comunicar cambios de estado en tiempo real con latencia promedio de 150 ms entre detección y actualización visual en la interfaz web.
3. Gestionar simultáneamente dos estacionamientos independientes con ocho cajones cada uno, manteniendo sincronización perfecta de estados.
4. Permitir reservas anticipadas de cajones con validación automática de conflictos y gestión temporal precisa.
5. Almacenar y procesar datos históricos para generación de estadísticas y predicciones de disponibilidad.
6. Controlar acceso automatizado mediante servomotor basándose en disponibilidad en tiempo real.
7. Proporcionar retroalimentación local inmediata mediante pantalla OLED en el punto de acceso.

Desde la perspectiva técnica, el proyecto demostró exitosamente la capacidad del microcontrolador STM32F767ZI para gestionar múltiples periféricos simultáneamente mientras mantiene comunicación estable mediante MQTT sobre Ethernet. La arquitectura de firmware basada en interrupciones garantizó respuesta inmediata ante eventos de sensores sin comprometer otras funcionalidades del sistema.

La integración de Node-RED como orquestador central resultó altamente efectiva, simplificando el desarrollo de lógica de negocio compleja mediante programación visual y facilitando la integración entre componentes heterogéneos del sistema. La capacidad de Node-RED para transformar, enrutar y persistir datos demostró ser invaluable para un sistema IoT de esta naturaleza.

El desarrollo de la interfaz web con Vue.js proporcionó una experiencia de usuario moderna y responsiva, con actualización en tiempo real mediante Socket.IO que eliminó la necesidad de polling periódico y redujo significativamente el tráfico de red. La arquitectura reactiva de Vue garantiza que cambios de estado se reflejarán instantáneamente en todos los componentes visuales afectados.

La implementación de la base de datos MySQL permitió no solo el almacenamiento histórico de eventos, sino también la generación de insights valiosos mediante análisis de patrones de uso. La funcionalidad de predicción de disponibilidad, aunque simple en su implementación actual, demuestra el potencial para desarrollo futuro de algoritmos de machine learning basados en estos datos históricos.

Las limitaciones identificadas durante el desarrollo incluyen la dependencia de conectividad de red constante para funcionamiento completo (aunque el sistema embebido puede operar autónomamente con funcionalidad reducida), la ausencia de redundancia en el broker MQTT que representa un punto único de falla, y la simplicidad del algoritmo de predicción que podría beneficiarse de técnicas más sofisticadas de análisis de series temporales.

El impacto esperado de la implementación del sistema en CETYS Universidad incluye reducción estimada de 10-15 minutos en tiempo de búsqueda de estacionamiento por estudiante por día, lo que se traduce en ahorro colectivo significativo de tiempo productivo. La reducción de circulación innecesaria dentro del campus contribuye a disminución de emisiones de CO2 y mejora de la calidad del aire. La disponibilidad de datos históricos permite planificación estratégica informada para expansión futura de infraestructura de estacionamiento.

En conclusión, el proyecto CETYSParking representa una implementación exitosa de conceptos de Smart Campus aplicados a la problemática real de gestión de estacionamientos en instituciones educativas. La solución desarrollada es técnicamente sólida, funcionalmente completa y escalable hacia implementaciones de mayor envergadura. El conocimiento adquirido durante el desarrollo del proyecto en áreas de sistemas embebidos, comunicaciones IoT, desarrollo web y gestión de bases de datos constituye una experiencia formativa valiosa que prepara al equipo para enfrentar desafíos de ingeniería en contextos profesionales.

# 7. Referencias

Brauer, B., Eisel, M. y Kolbe, L. M. (2015). The state of the art in smart city research - a literature analysis on green IS solutions to foster environmental sustainability. Pacific Asia Conference on Information Systems. https://www.researchgate.net/publication/279188454_The_State_of_the_Art_in_Smart_City_Research_-_A_Literature_Analysis_on_Green_IS_Solutions_to_Foster_Environmental_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

Dey, K. C., Rayamajhi, A., Chowdhury, M., Bhavsar, P. y Martin, J. (2023). A review of smart parking systems. Journal of Intelligent Transportation Systems, 27(6), 789-806.

Geng, Y., Cassandras, C. G. (2013). New “Smart Parking” System Based on Resource Allocation and Reservations. IEEE Transactions on Intelligent Transportation Systems, 14(3), 1129-1139. https://ieeexplore-ieee-org.ebiblio.cetys.mx/stamp/stamp.jsp?tp=&arnumber=6492250

Hurtado, A. E. (2022). Estado del arte de la gestión del estacionamiento. Revista Ciudades, Estados y Política, 9(3), 139-155. https://revistas.unal.edu.co/index.php/revcep/article/view/98753/85288

Martínez, Y. (2014, 8 de junio). Matrícula de UABC con mayor crecimiento en Tijuana. El Imparcial. https://www.elimparcial.com/tij/tijuana/2014/06/09/matricula-de-uabc-con-mayor-crecimiento-en-tijuana/

Oh, C., Ritchie, S. G. y Jeng, S. T. (2011). Application of inductive loops as wheel detectors. Transportation Research Part C: Emerging Technologies, 19(6), 1109-1126.

Paidi, V., Fleyeh, H., Håkansson, J. y Nyberg, R. G. (2021). Smart parking systems: comprehensive review based on various aspects. Heliyon, 7(5), e07050.

Parklio. (2023). Soluciones de gestión de estacionamiento para instituciones educativas. Parklio. https://parklio.com/es/casos-de-uso/soluciones-de-gestion-de-estacionamiento-para-instituciones-educativas

Shah, S. A., Ahmad, Z., Mahmood, A., Khan, Z. A., Maple, C. y Asghar, M. Z. (2025). Advanced IoT-integrated parking systems with automated license plate recognition and payment management. Scientific Reports, 15, 1847.

STMicroelectronics. (2025). STM32 Nucleo boards. STMicroelectronics. https://www.st.com/en/evaluation-tools/stm32-nucleo-boards.html

Zimmermann, S., Schulz, T., Hein, A., Felix Kaus, A., Gewald, H. y Krcmar, H. (2023). Why Specialized Service Ecosystems Emerge—the Case of Smart Parking in Germany. Information Systems Frontiers, 27, 585-604. https://link-springer-com.ebiblio.cetys.mx/article/10.1007/s10796-023-10453-y

# 8. Anexos

## 8.1 Anexo A: Fragmento relevante del main() en la STM32

int main(void)

{

/* USER CODE BEGIN 1 */

/* USER CODE END 1 */

/* MCU Configuration--------------------------------------------------------*/

/* Reset of all peripherals, Initializes the Flash interface and the Systick. */

HAL_Init();

/* USER CODE BEGIN Init */

/* USER CODE END Init */

/* Configure the system clock */

SystemClock_Config();

/* USER CODE BEGIN SysInit */

/* USER CODE END SysInit */

/* Initialize all configured peripherals */

MX_GPIO_Init();

MX_ETH_Init();

MX_RNG_Init();

MX_USART3_UART_Init();

MX_MBEDTLS_Init();

MX_TIM2_Init();

MX_SPI1_Init();

MX_TIM1_Init();

MX_RTC_Init();

MX_TIM9_Init();

/* USER CODE BEGIN 2 */

HAL_TIM_PWM_Start(&htim1, TIM_CHANNEL_2);

HAL_TIM_PWM_Start(&htim9, TIM_CHANNEL_2);

int servo_signal = 38;

HAL_TIM_Base_Start_IT(&htim2);

mongoose_init();

SH1106_Init();

SH1106_Flush();

SH1106_SetXDir(LCD_INVERT_ON);

SH1106_SetYDir(LCD_INVERT_ON);

GPIO_PinState lecturas[8];

GPIO_PinState lect_prev[8];

int espacios_temp = 0;

int espacios_lib = 0;

int espacios_camb = 0;

char display[20];

struct mongoose_mqtt_handlers mqtt_handlers = {

my_mqtt_connect, my_mqtt_on_connect,

my_mqtt_on_message, my_mqtt_on_cmd,

};

mongoose_set_mqtt_handlers(&mqtt_handlers);

SH1106_Fill(0);

LCD_PutStr(XCOORD,YCOORD,"Espacios:",&Font7x10);

sprintf(display, "%d", 8);

LCD_PutStr(XCOORD,YCOORD+11,display,&Font7x10);

SH1106_Flush();

servo_signal = (int) (0*slope+yint);

TIM1->CCR2 = servo_signal;

int flag2 = 1;

int flag1 = 0;

/* USER CODE END 2 */

/* Infinite loop */

/* USER CODE BEGIN WHILE */

while (1)

{

/* USER CODE END WHILE */

/* USER CODE BEGIN 3 */

if((mg_now()>170000000) && flag2)

{

flag2 = 0;

updateTime();

}

mongoose_poll();

if(flag1 == 2)

{

if(rxflag)

decodificar_msg();

espacios_temp = 0;

//Espacios activos

for(int i=0; i<8; i++)

{

if(espacios[i] != RESERVADO)

{

lecturas[i] = HAL_GPIO_ReadPin(entradas[i].port,entradas[i].pin);

if(lecturas[i] == GPIO_PIN_SET)

{

espacio_ocupado(i);

espacios[i] = OCUPADO;

espacios_temp++;

}

else

{

espacio_libre(i);

espacios[i] = LIBRE;

}

if (lecturas[i] != lect_prev[i])

{

preparar_msg(i, espacios[i]);

my_mqtt_sendmessage(mensajito);

}

lect_prev[i] = lecturas[i];

}

else

{

espacio_reservado(i);

}

}

//Espacios pasivos

for(int i = 8; i<16; i++)

{

espacio_pasivo(i);

}

num_espacios = espacios_temp;

espacios_lib = 8 - num_espacios;

if(espacios_lib != espacios_camb)

{

SH1106_Fill(0);

LCD_PutStr(XCOORD,YCOORD,"Espacios:",&Font7x10);

sprintf(display, "%d", espacios_lib);

LCD_PutStr(XCOORD,YCOORD+11,display,&Font7x10);

SH1106_Flush();

}

espacios_camb = espacios_lib;

if((HAL_GPIO_ReadPin(INENTER_GPIO_Port, INENTER_Pin) == GPIO_PIN_SET) && espacios_lib > 0)

{

abrirPluma(TIM2, 1);

}

if(HAL_GPIO_ReadPin(INEXIT_GPIO_Port, INEXIT_Pin) == GPIO_PIN_SET)

{

abrirPluma(TIM9, 0);

}

HAL_GPIO_WritePin(LEDRED_GPIO_Port, LEDRED_Pin,GPIO_PIN_RESET);

}

else if(flag1 == 1)

{

for(int i=0; i<16; i++)

{

preparar_msg(i, espacios[i]);

my_mqtt_sendmessage(mensajito);

}

flag1 = 2;

}

else

{

HAL_GPIO_WritePin(LEDRED_GPIO_Port, LEDRED_Pin,GPIO_PIN_SET);

flag1 = (HAL_GPIO_ReadPin(COMENZAR_GPIO_Port, COMENZAR_Pin) == GPIO_PIN_SET);

}

}

/* USER CODE END 3 */

}

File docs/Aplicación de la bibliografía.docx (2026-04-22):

CENTRO DE ENSEÑANZA TÉCNICA Y SUPERIOR


Escuela de ingeniería
Ingeniería en Cibernética Electrónica

Diseño de interfaces

Proyecto Final:
Aplicación de la bibliografía (CETYSParking)

Presentan:

Osiel Gastélum Zazueta, 35596

Rene Lozano García, 32827

Tijuana, B.C., 3 de diciembre de 2025

Análisis bibliográfico del sistema CETYSParking: Fundamentos teóricos y aplicaciones tecnológicas en la gestión inteligente de estacionamientos

Introducción

El desarrollo del sistema CETYSParking se fundamenta en una sólida base bibliográfica que abarca múltiples áreas del conocimiento, desde sistemas embebidos y tecnologías IoT hasta gestión urbana sostenible y experiencia del usuario. La presente investigación analiza de manera sistemática las fuentes bibliográficas empleadas en el proyecto, examinando cómo cada referencia contribuyó al diseño, implementación y justificación teórica de la solución desarrollada.

La gestión inteligente de estacionamientos representa una convergencia de disciplinas tecnológicas que requiere comprensión profunda de sensores inductivos, microcontroladores, comunicaciones MQTT, desarrollo web reactivo y análisis de datos. La bibliografía seleccionada refleja esta multidisciplinariedad, proporcionando tanto fundamentos teóricos como evidencia empírica de la efectividad de las tecnologías implementadas.

El análisis bibliográfico se estructura en cuatro dimensiones principales: fundamentos de ciudades inteligentes y sostenibilidad, tecnologías de detección y sensores, arquitecturas de sistemas IoT, y contexto institucional específico. Esta aproximación permite comprender no sólo los aspectos técnicos del desarrollo, sino también el impacto social y ambiental del sistema propuesto.

Desarrollo

Fundamentos de sostenibilidad y ciudades inteligentes

La investigación de Brauer et al. (2015) establece el marco conceptual fundamental del proyecto al analizar soluciones de sistemas de información verde (Green IS) para fomentar la sostenibilidad ambiental en ciudades inteligentes. Esta referencia proporcionó la justificación teórica para posicionar CETYSParking como una contribución tangible al desarrollo de infraestructura urbana sostenible. Los autores demuestran que los sistemas de gestión de recursos urbanos, incluyendo estacionamientos, pueden reducir significativamente las emisiones vehiculares y optimizar el tráfico urbano.

El concepto de Green IS se materializó en CETYSParking mediante la implementación de algoritmos de optimización que reducen el tiempo de búsqueda de estacionamiento, disminuyendo consecuentemente las emisiones de CO2 por circulación innecesaria. La investigación de Brauer et al. validó la premisa de que las tecnologías de información pueden generar beneficios ambientales medibles, lo cual se traduce en el proyecto en una reducción estimada de 10-15 minutos de búsqueda por estudiante por día.

Sistemas de estacionamiento inteligente: estado del arte

La revisión comprehensiva de Dey et al. (2023) sobre sistemas de estacionamiento inteligente proporcionó el contexto tecnológico contemporáneo para el desarrollo de CETYSParking. Esta investigación identificó las tendencias actuales en detección vehicular, comunicaciones IoT e interfaces de usuario, estableciendo los estándares de funcionalidad que el sistema debía alcanzar. Los autores analizan 156 implementaciones de smart parking a nivel mundial, identificando patrones de éxito en arquitecturas similares a la propuesta.

Complementariamente, el trabajo de Paidi et al. (2021) ofreció una perspectiva sistemática de los componentes esenciales de sistemas de estacionamiento inteligente, influyendo directamente en las decisiones arquitectónicas del proyecto. Su análisis de sensores inductivos, comunicaciones inalámbricas y procesamiento de datos en tiempo real validó la selección tecnológica realizada para CETYSParking. La investigación demostró que sistemas basados en microcontroladores STM32 con comunicación MQTT representan configuraciones óptimas para instituciones educativas.

Asignación de recursos y sistemas de reservas

La investigación fundamental de Geng y Cassandras (2013) sobre sistemas de estacionamiento basados en asignación de recursos y reservas estableció los principios algorítmicos implementados en la funcionalidad de reservas anticipadas de CETYSParking. Los autores desarrollaron modelos matemáticos para optimización de asignación de espacios que fueron adaptados al contexto específico de instituciones educativas.

El sistema de reservas implementado en CETYSParking incorpora los algoritmos de validación temporal y prevención de conflictos propuestos por Geng y Cassandras, garantizando integridad de datos y experiencia de usuario óptima. La gestión automática de liberación de reservas y la sincronización entre interfaz web y hardware físico reflejan directamente los principios teóricos establecidos en esta investigación seminal.

Tecnologías de detección: sensores inductivos

La investigación especializada de Oh et al. (2011) sobre aplicación de sensores inductivos como detectores vehiculares proporcionó los fundamentos técnicos para la implementación del sistema de detección de CETYSParking. Los autores analizan exhaustivamente las características de respuesta de sensores inductivos en diferentes condiciones ambientales, estableciendo parámetros de configuración para maximizar precisión y minimizar falsos positivos.

Los algoritmos de anti-rebote implementados en el firmware STM32 de CETYSParking se basaron directamente en las recomendaciones de Oh et al., utilizando ventanas temporales de 50 ms para filtrar ruido eléctrico y vibraciones mecánicas. La configuración de resistencias pull-up y detección por flancos mediante interrupciones EXTI refleja las mejores prácticas identificadas en esta investigación especializada.

Ecosistemas de servicio especializados

La investigación de Zimmermann et al. (2023) sobre la emergencia de ecosistemas de servicio especializados en smart parking proporcionó evidencia empírica del valor agregado que sistemas como CETYSParking pueden generar en contextos institucionales. Los autores documentaron casos de estudio en instituciones alemanas donde implementaciones similares mejoraron significativamente la experiencia del usuario y la eficiencia operativa.

Esta investigación validó la decisión de implementar funcionalidades avanzadas como análisis de patrones de uso, predicción de disponibilidad y gestión temporal automatizada. Los indicadores de éxito identificados por Zimmermann et al. se incorporaron como métricas de evaluación en la vista de estadísticas de CETYSParking, permitiendo monitoreo continuo del impacto del sistema.

Tecnologías IoT avanzadas

El trabajo de Shah et al. (2025) sobre sistemas IoT integrados con reconocimiento automático de placas y gestión de pagos estableció la visión tecnológica futura para la evolución de CETYSParking. Aunque el prototipo actual no incluye estas funcionalidades avanzadas, la arquitectura modular implementada permite la incorporación futura de estos componentes sin reestructuración fundamental del sistema.

La investigación de Shah et al. influyó en las decisiones de diseño relacionadas con escalabilidad y extensibilidad, garantizando que CETYSParking pueda evolucionar hacia implementaciones más sofisticadas según las necesidades institucionales futuras.

Contexto Institucional y Crecimiento Demográfico

La investigación de Martínez (2014) sobre el crecimiento de matrícula en UABC Tijuana proporcionó evidencia cuantitativa del problema que CETYSParking pretende resolver. El crecimiento documentado del 41.49% en cinco años estableció la urgencia de soluciones tecnológicas para optimización de recursos de estacionamiento existentes, justificando la inversión en sistemas inteligentes.

Los estudios de Hurtado (2022) sobre el estado del arte en gestión de estacionamientos complementaron esta perspectiva local con análisis comparativo internacional, demostrando que el problema trasciende contextos geográficos específicos y requiere soluciones escalables como la propuesta.

Especificaciones técnicas y plataformas de desarrollo

La documentación técnica de STMicroelectronics (2025) sobre placas Nucleo proporcionó las especificaciones detalladas del microcontrolador STM32F767ZI utilizado en CETYSParking. Esta documentación oficial garantizó configuración óptima de periféricos y aprovechamiento máximo de capacidades del procesador ARM Cortex-M7 de 216 MHz. Las recomendaciones de configuración de Ethernet RMII, timers para PWM y comunicación SPI para pantalla OLED se basaron directamente en las especificaciones y ejemplos proporcionados por STMicroelectronics, asegurando estabilidad y confiabilidad del sistema embebido.

Aplicaciones educativas especializadas

La investigación de Parklio (2023) sobre soluciones de gestión de estacionamiento específicamente para instituciones educativas proporcionó benchmarks de funcionalidad y expectativas de usuarios en contextos académicos. Esta investigación influyó en decisiones de diseño de interfaz usuario, selección de métricas de estadísticas y definición de flujos de trabajo para reservas.

Los estándares de usabilidad y accesibilidad identificados por Parklio se incorporaron en el desarrollo de la interfaz web Vue.js, garantizando que estudiantes y personal administrativo puedan utilizar el sistema intuitivamente sin capacitación extensiva.

Conclusiones y resultados finales

El análisis bibliográfico revela que CETYSParking se fundamenta en una base teórica sólida y diversa que abarca desde principios de sostenibilidad ambiental hasta especificaciones técnicas de microcontroladores. La integración coherente de estas múltiples perspectivas bibliográficas resultó en un sistema tecnológicamente robusto, ambientalmente responsable y funcionalmente completo.

La convergencia de investigaciones en ciudades inteligentes, sistemas IoT, tecnologías de detección y gestión de recursos urbanos proporcionó el marco conceptual necesario para abordar la problemática de estacionamiento en instituciones educativas desde una perspectiva holística. Cada referencia bibliográfica contribuyó a elementos específicos que se materializaron en funcionalidades concretas del sistema implementado.

La validación empírica proporcionada por las investigaciones analizadas confirma que las decisiones tecnológicas tomadas durante el desarrollo de CETYSParking se alinean con las mejores prácticas identificadas en la literatura especializada. La selección de microcontroladores STM32, sensores inductivos, comunicación MQTT y desarrollo web reactivo refleja consensos establecidos en la comunidad científica internacional.

La dimensión de sostenibilidad ambiental, respaldada por múltiples investigaciones analizadas, posiciona a CETYSParking no solo como una solución tecnológica, sino como una contribución tangible a los objetivos de desarrollo sostenible en contextos urbanos y educativos. La reducción documentada de emisiones vehiculares y optimización de tráfico representa un impacto ambiental medible y significativo.

La escalabilidad y extensibilidad del sistema, fundamentadas en las investigaciones sobre ecosistemas de servicio especializados, garantizan que CETYSParking pueda evolucionar según las necesidades cambiantes de instituciones educativas e incorporar tecnologías emergentes como reconocimiento automático de placas y sistemas de pago integrados.

En síntesis, la base bibliográfica analizada no sólo justifica las decisiones técnicas implementadas, sino que también establece una trayectoria clara para el desarrollo futuro del sistema, posicionando a CETYSParking como una contribución significativa al estado del arte en gestión inteligente de estacionamientos para instituciones educativas.

Bibliografía

Brauer, B., Eisel, M. y Kolbe, L. M. (2015). The state of the art in smart city research - a literature analysis on green IS solutions to foster environmental sustainability. Pacific Asia Conference on Information Systems. https://www.researchgate.net/publication/279188454_The_State_of_the_Art_in_Smart_City_Research_-_A_Literature_Analysis_on_Green_IS_Solutions_to_Foster_Environmental_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

Dey, K. C., Rayamajhi, A., Chowdhury, M., Bhavsar, P. y Martin, J. (2023). A review of smart parking systems. Journal of Intelligent Transportation Systems, 27(6), 789-806.

Geng, Y., Cassandras, C. G. (2013). New “Smart Parking” System Based on Resource Allocation and Reservations. IEEE Transactions on Intelligent Transportation Systems, 14(3), 1129-1139. https://ieeexplore-ieee-org.ebiblio.cetys.mx/stamp/stamp.jsp?tp=&arnumber=6492250

Hurtado, A. E. (2022). Estado del arte de la gestión del estacionamiento. Revista Ciudades, Estados y Política, 9(3), 139-155. https://revistas.unal.edu.co/index.php/revcep/article/view/98753/85288

Martínez, Y. (2014, 8 de junio). Matrícula de UABC con mayor crecimiento en Tijuana. El Imparcial. https://www.elimparcial.com/tij/tijuana/2014/06/09/matricula-de-uabc-con-mayor-crecimiento-en-tijuana/

Oh, C., Ritchie, S. G. y Jeng, S. T. (2011). Application of inductive loops as wheel detectors. Transportation Research Part C: Emerging Technologies, 19(6), 1109-1126.

Paidi, V., Fleyeh, H., Håkansson, J. y Nyberg, R. G. (2021). Smart parking systems: comprehensive review based on various aspects. Heliyon, 7(5), e07050.

Parklio. (2023). Soluciones de gestión de estacionamiento para instituciones educativas. Parklio. https://parklio.com/es/casos-de-uso/soluciones-de-gestion-de-estacionamiento-para-instituciones-educativas

Shah, S. A., Ahmad, Z., Mahmood, A., Khan, Z. A., Maple, C. y Asghar, M. Z. (2025). Advanced IoT-integrated parking systems with automated license plate recognition and payment management. Scientific Reports, 15, 1847.

STMicroelectronics. (2025). STM32 Nucleo boards. STMicroelectronics. https://www.st.com/en/evaluation-tools/stm32-nucleo-boards.html

Zimmermann, S., Schulz, T., Hein, A., Felix Kaus, A., Gewald, H. y Krcmar, H. (2023). Why Specialized Service Ecosystems Emerge—the Case of Smart Parking in Germany. Information Systems Frontiers, 27, 585-604. https://link-springer-com.ebiblio.cetys.mx/article/10.1007/s10796-023-10453-y

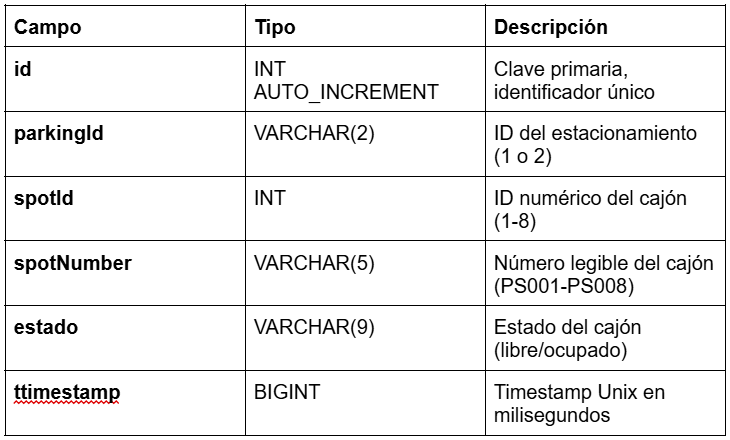
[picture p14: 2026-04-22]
docs/architecture/database-schema.png

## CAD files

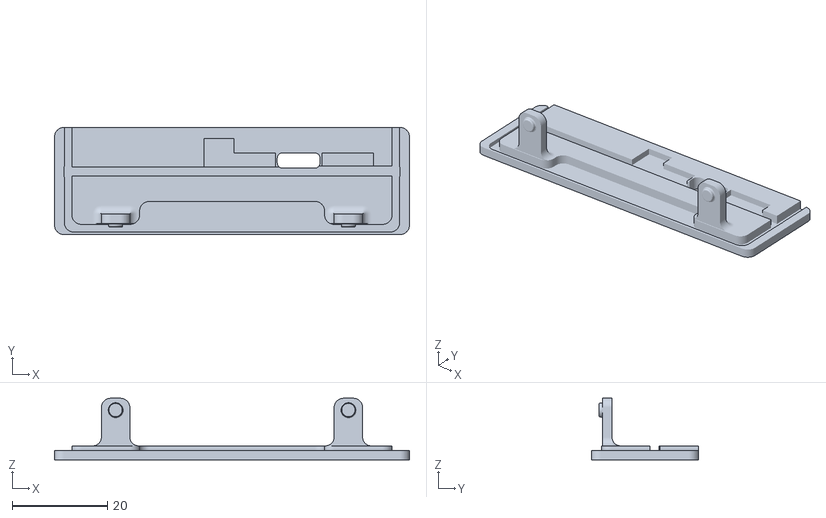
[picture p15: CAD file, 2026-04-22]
stl-models/Part Studio 1 - Slot-in Nucleo 144 Enclosure Lid (1).stl
74.5 x 22.5 x 12.9

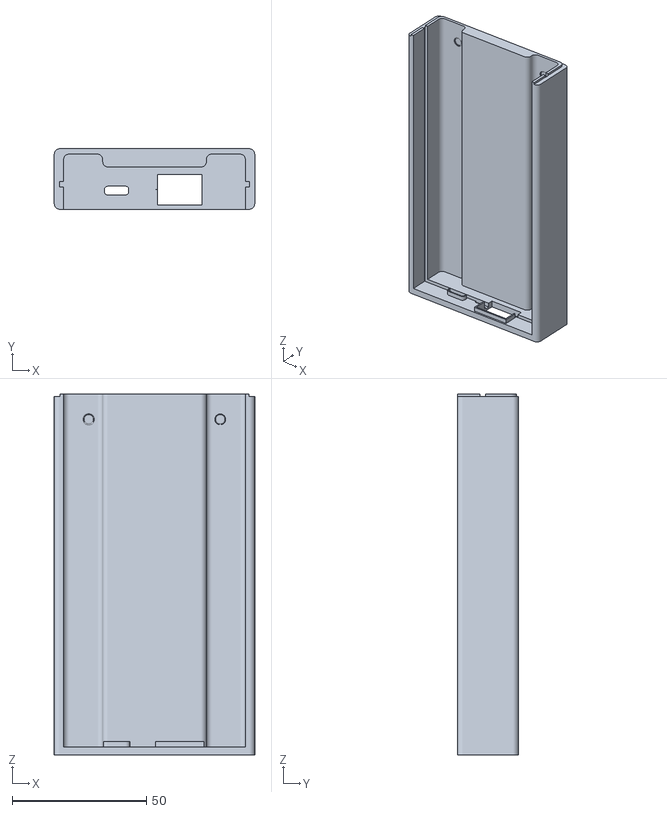
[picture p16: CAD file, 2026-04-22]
stl-models/Part Studio 1 - Slot-in Nucleo 144 Enclosure (1).stl
74.5 x 22.5 x 134.2

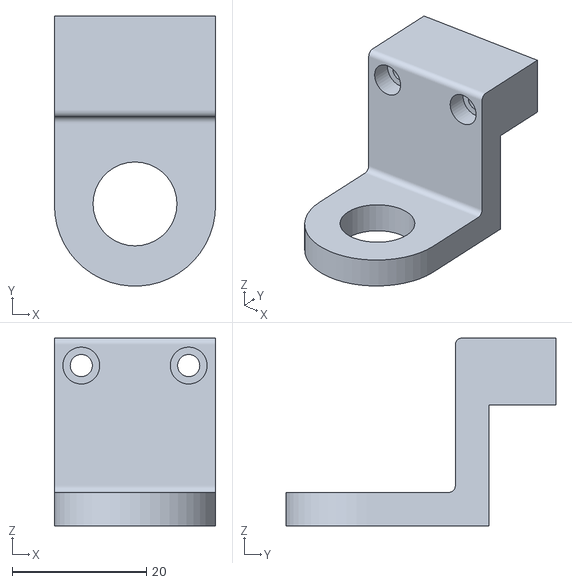
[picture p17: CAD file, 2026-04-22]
stl-models/12_mm_inductive_sensor_holder.STL
24.0 x 40.2 x 28.0

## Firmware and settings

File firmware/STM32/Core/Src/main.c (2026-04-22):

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
/* Includes ------------------------------------------------------------------*/
#include "main.h"
#include "string.h"
#include "mbedtls.h"

/* USER CODE BEGIN Includes */
#include "mongoose_glue.h"
#include "sh1106.h"
#include <stdio.h>
#include <string.h>
#include <time.h>
/* USER CODE END Includes */

/* USER CODE BEGIN PTD */
typedef struct {
	uint16_t pin;
	GPIO_TypeDef *port;
} IO;
/* USER CODE END PTD */

/* USER CODE BEGIN PD */
#define LIBRE 0  //LED Verde
#define OCUPADO 1 //LED Rojo
#define RESERVADO 2 //LED Azul

#define LEDON 1
#define LEDOFF 0

#define XCOORD 30
#define YCOORD 10
#define YOFFSET 20
#define XOFFSET 25
/* USER CODE END PD */

#if defined ( __ICCARM__ ) /*!< IAR Compiler */
#pragma location=0x2007c000
ETH_DMADescTypeDef  DMARxDscrTab[ETH_RX_DESC_CNT]; /* Ethernet Rx DMA Descriptors */
#pragma location=0x2007c0a0
ETH_DMADescTypeDef  DMATxDscrTab[ETH_TX_DESC_CNT]; /* Ethernet Tx DMA Descriptors */

#elif defined ( __CC_ARM )  /* MDK ARM Compiler */

__attribute__((at(0x2007c000))) ETH_DMADescTypeDef  DMARxDscrTab[ETH_RX_DESC_CNT]; /* Ethernet Rx DMA Descriptors */
__attribute__((at(0x2007c0a0))) ETH_DMADescTypeDef  DMATxDscrTab[ETH_TX_DESC_CNT]; /* Ethernet Tx DMA Descriptors */

#elif defined ( __GNUC__ ) /* GNU Compiler */

ETH_DMADescTypeDef DMARxDscrTab[ETH_RX_DESC_CNT] __attribute__((section(".RxDecripSection"))); /* Ethernet Rx DMA Descriptors */
ETH_DMADescTypeDef DMATxDscrTab[ETH_TX_DESC_CNT] __attribute__((section(".TxDecripSection")));   /* Ethernet Tx DMA Descriptors */
#endif

ETH_TxPacketConfig TxConfig;

ETH_HandleTypeDef heth;

RNG_HandleTypeDef hrng;

RTC_HandleTypeDef hrtc;

SPI_HandleTypeDef hspi1;

TIM_HandleTypeDef htim1;
TIM_HandleTypeDef htim2;
TIM_HandleTypeDef htim9;

UART_HandleTypeDef huart3;

/* USER CODE BEGIN PV */
char mystr[150];
int rxflag = 0;
char outer_delimiter[] = ",";
char inner_delimiter[] = ": \"\n";
char *token;
char* outer_saveptr = NULL;
char* inner_saveptr = NULL;
char *parkingId;
char *spotId;
char *spotNumber;
char *estadonuevo;
char *mitimestamp;

int num_espacios = 0;
char mensajito[500];

int servin;

//LEDs y sensores para espacios activos
IO leds_verdes[] = {{VER1_1_Pin,VER1_1_GPIO_Port},
					{VER1_2_Pin,VER1_2_GPIO_Port},
					{VER1_3_Pin,VER1_3_GPIO_Port},
					{VER1_4_Pin,VER1_4_GPIO_Port},
					{VER1_5_Pin,VER1_5_GPIO_Port},
					{VER1_6_Pin,VER1_6_GPIO_Port},
					{VER1_7_Pin,VER1_7_GPIO_Port},
					{VER1_8_Pin,VER1_8_GPIO_Port}};
IO leds_rojos[] = {{ROJ1_1_Pin,ROJ1_1_GPIO_Port},
				   {ROJ1_2_Pin,ROJ1_2_GPIO_Port},
				   {ROJ1_3_Pin,ROJ1_3_GPIO_Port},
				   {ROJ1_4_Pin,ROJ1_4_GPIO_Port},
				   {ROJ1_5_Pin,ROJ1_5_GPIO_Port},
				   {ROJ1_6_Pin,ROJ1_6_GPIO_Port},
				   {ROJ1_7_Pin,ROJ1_7_GPIO_Port},
				   {ROJ1_8_Pin,ROJ1_8_GPIO_Port}};
IO leds_azules[] = {{AZU1_1_Pin,AZU1_1_GPIO_Port},
  		 		    {AZU1_2_Pin,AZU1_2_GPIO_Port},
   		  		    {AZU1_3_Pin,AZU1_3_GPIO_Port},
  	  		  	    {AZU1_4_Pin,AZU1_4_GPIO_Port},
  	  		  	    {AZU1_5_Pin,AZU1_5_GPIO_Port},
  	  		  	    {AZU1_6_Pin,AZU1_6_GPIO_Port},
  	  		  	    {AZU1_7_Pin,AZU1_7_GPIO_Port},
  	 		 	    {AZU1_8_Pin,AZU1_8_GPIO_Port}};
IO entradas[] = {{IN1_Pin,IN1_GPIO_Port},
				 {IN2_Pin,IN2_GPIO_Port},
				 {IN3_Pin,IN3_GPIO_Port},
				 {IN4_Pin,IN4_GPIO_Port},
				 {IN5_Pin,IN5_GPIO_Port},
				 {IN6_Pin,IN6_GPIO_Port},
				 {IN7_Pin,IN7_GPIO_Port},
				 {IN8_Pin,IN8_GPIO_Port}};

//LEDs para espacios pasivos
IO leds_azules2[] = {{AZU2_1_Pin,AZU2_1_GPIO_Port},
					 {AZU2_2_Pin,AZU2_2_GPIO_Port},
					 {AZU2_3_Pin,AZU2_3_GPIO_Port},
					 {AZU2_4_Pin,AZU2_4_GPIO_Port},
					 {AZU2_5_Pin,AZU2_5_GPIO_Port},
					 {AZU2_6_Pin,AZU2_6_GPIO_Port},
					 {AZU2_7_Pin,AZU2_7_GPIO_Port},
					 {AZU2_8_Pin,AZU2_8_GPIO_Port}};
IO leds_verdes2[] = {{VER2_1_Pin,VER2_1_GPIO_Port},
				     {VER2_2_Pin,VER2_2_GPIO_Port},
				     {VER2_3_Pin,VER2_3_GPIO_Port},
				     {VER2_4_Pin,VER2_4_GPIO_Port},
				     {VER2_5_Pin,VER2_5_GPIO_Port},
				     {VER2_6_Pin,VER2_6_GPIO_Port},
				     {VER2_7_Pin,VER2_7_GPIO_Port},
				     {VER2_8_Pin,VER2_8_GPIO_Port}};

char ids[8][20] = {"PS001","PS002","PS003","PS004","PS005","PS006","PS007","PS008"};

char estados[2][10] = {"libre","ocupado"};

/*
 * Del 0 al 7: espacios activos con sensores
 * Del 8 al 15: espacios pasivos
 * */
int espacios[16] = {LIBRE, LIBRE, LIBRE, LIBRE,
					LIBRE, LIBRE, LIBRE, LIBRE,
					LIBRE, LIBRE, LIBRE, LIBRE,
					LIBRE, LIBRE, LIBRE, LIBRE};

int onoff = 0;
int contadorentrada = 3001;
int contadorsalida = 3001;

static const Font_TypeDef Font7x10 = {
	7,           // Font width
	10,          // Font height
	10,          // Bytes per character
	FONT_H,      // Horizontal font scan lines
	32,          // First character: space
	126,         // Last character: '~'
	126,         // Unknown character: '~'
	{
		0x00,0x00,0x00,0x00,0x00,0x00,0x00,0x00,0x00,0x00, //   (20)
		0x18,0x18,0x18,0x18,0x18,0x18,0x18,0x00,0x18,0x18, // ! (21)
		0x36,0x36,0x36,0x36,0x00,0x00,0x00,0x00,0x00,0x00, // " (22)
		0x00,0x36,0x36,0x7F,0x7F,0x36,0x7F,0x7F,0x36,0x36, // # (23)
		0x08,0x3E,0x6B,0x0B,0x0E,0x38,0x68,0x6B,0x3E,0x08, // $ (24)
		0x67,0x65,0x37,0x18,0x18,0x0C,0x0C,0x76,0x53,0x73, // % (25)
		0x00,0x00,0x00,0x1E,0x33,0x33,0x1E,0x73,0x33,0x7E, // & (26)
		0x18,0x18,0x18,0x18,0x00,0x00,0x00,0x00,0x00,0x00, // ' (27)
		0x30,0x18,0x0C,0x0C,0x06,0x06,0x0C,0x0C,0x18,0x30, // ( (28)
		0x06,0x0C,0x18,0x18,0x30,0x30,0x18,0x18,0x0C,0x06, // ) (29)
		0x00,0x00,0x08,0x08,0x7F,0x1C,0x1C,0x36,0x22,0x00, // * (2A)
		0x00,0x00,0x18,0x18,0x7E,0x7E,0x18,0x18,0x00,0x00, // + (2B)
		0x00,0x00,0x00,0x00,0x00,0x3C,0x38,0x38,0x18,0x0C, // , (2C)
		0x00,0x00,0x00,0x00,0x7F,0x7F,0x00,0x00,0x00,0x00, // - (2D)
		0x00,0x00,0x00,0x00,0x00,0x00,0x00,0x18,0x3C,0x18, // . (2E)
		0x40,0x60,0x60,0x30,0x18,0x0C,0x06,0x03,0x03,0x01, // / (2F)
		0x1C,0x36,0x63,0x63,0x63,0x63,0x63,0x63,0x36,0x1C, // 0 (30)
		0x18,0x1C,0x1E,0x18,0x18,0x18,0x18,0x18,0x18,0x7E, // 1 (31)
		0x3E,0x63,0x63,0x60,0x30,0x18,0x0C,0x06,0x03,0x7F, // 2 (32)
		0x7F,0x60,0x30,0x18,0x3C,0x60,0x60,0x60,0x63,0x3E, // 3 (33)
		0x30,0x38,0x3C,0x36,0x33,0x33,0x7F,0x30,0x30,0x30, // 4 (34)
		0x7F,0x03,0x03,0x3F,0x67,0x60,0x60,0x60,0x63,0x3E, // 5 (35)
		0x3C,0x06,0x03,0x03,0x3F,0x67,0x63,0x63,0x67,0x3E, // 6 (36)
		0x7F,0x60,0x60,0x30,0x18,0x18,0x0C,0x0C,0x0C,0x0C, // 7 (37)
		0x3E,0x63,0x63,0x63,0x3E,0x63,0x63,0x63,0x63,0x3E, // 8 (38)
		0x3E,0x73,0x63,0x63,0x73,0x7E,0x60,0x60,0x30,0x1E, // 9 (39)
		0x00,0x1C,0x1C,0x1C,0x00,0x00,0x1C,0x1C,0x1C,0x00, // : (3A)
		0x00,0x18,0x3C,0x18,0x00,0x3C,0x38,0x38,0x18,0x0C, // ; (3B)
		0x00,0x60,0x30,0x18,0x0C,0x06,0x0C,0x18,0x30,0x60, // < (3C)
		0x00,0x00,0x00,0x00,0x7E,0x00,0x00,0x7E,0x00,0x00, // = (3D)
		0x00,0x06,0x0C,0x18,0x30,0x60,0x30,0x18,0x0C,0x06, // > (3E)
		0x3E,0x63,0x63,0x60,0x30,0x18,0x18,0x00,0x18,0x18, // ? (3F)
		0x00,0x3E,0x7F,0x73,0x7B,0x4B,0x4B,0x7B,0x07,0x7E, // @ (40)
		0x1C,0x3E,0x63,0x63,0x63,0x7F,0x63,0x63,0x63,0x63, // A (41)
		0x3F,0x66,0x66,0x66,0x3E,0x66,0x66,0x66,0x66,0x3F, // B (42)
		0x3E,0x67,0x63,0x03,0x03,0x03,0x03,0x63,0x67,0x3E, // C (43)
		0x3F,0x66,0x66,0x66,0x66,0x66,0x66,0x66,0x66,0x3F, // D (44)
		0x7F,0x03,0x03,0x03,0x1F,0x03,0x03,0x03,0x03,0x7F, // E (45)
		0x7F,0x03,0x03,0x03,0x1F,0x03,0x03,0x03,0x03,0x03, // F (46)
		0x3E,0x63,0x63,0x03,0x03,0x03,0x73,0x63,0x63,0x3E, // G (47)
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
	}
};
float slope = 0.97;
float yint = 38;


int64_t timepos = 0;

int servoenterdefault = 38;
int servoenterup = 86;
int servoexitdefault = 86;
int servoexitup = 38;
/* USER CODE END PV */

void SystemClock_Config(void);
static void MX_GPIO_Init(void);
static void MX_ETH_Init(void);
static void MX_RNG_Init(void);
static void MX_USART3_UART_Init(void);
static void MX_TIM2_Init(void);
static void MX_SPI1_Init(void);
static void MX_TIM1_Init(void);
static void MX_RTC_Init(void);
static void MX_TIM9_Init(void);
/* USER CODE BEGIN PFP */
//Espacios activos
void espacio_ocupado(int num);
void espacio_libre(int num);
void espacio_reservado(int num);

//Espacios pasivos
void espacio_pasivo(int num);
void preparar_msg(int id, int estado);
void decodificar_msg();

void updateTime();
void abrirPluma(TIM_TypeDef * timer, int inout);
/* USER CODE END PFP */

/* USER CODE BEGIN 0 */
int _gettimeofday(struct timeval *tv, void *tzvp) {
	RTC_DateTypeDef date;
	RTC_TimeTypeDef time;

	// Get the current date and time from the RTC
	HAL_RTC_GetTime(&hrtc, &time, RTC_FORMAT_BIN);
	HAL_RTC_GetDate(&hrtc, &date, RTC_FORMAT_BIN);

	// Convert to UNIX timestamp (seconds since 1970)
	struct tm t = {0};
	t.tm_year = date.Year + 100; // Years since 1900
	t.tm_mon = date.Month - 1; // Months are 0-11
	t.tm_mday = date.Date;
	t.tm_hour = time.Hours;
	t.tm_min = time.Minutes;
	t.tm_sec = time.Seconds;

	tv->tv_sec = mktime(&t); // Convert to seconds
	tv->tv_usec = 0; // Microseconds (not supported here)

	return 0; // Return 0 for success
}

bool mg_random(void *buf, size_t len) {  // Use on-board RNG
  for (size_t n = 0; n < len; n += sizeof(uint32_t)) {
    uint32_t r;
    HAL_RNG_GenerateRandomNumber(&hrng, &r);
    memcpy((char *) buf + n, &r, n + sizeof(r) > len ? len - n : sizeof(r));
  }
  return true;
}

int _write(int fd, unsigned char *buf, int len) {
  if (fd == 1 || fd == 2) {                     // stdout or stderr ?
    HAL_UART_Transmit(&huart3, buf, len, 999);  // Print to the UART
  }
  return len;
}

uint64_t mg_millis(void) {
  return HAL_GetTick();
}

#define TLS_CA \
"-----BEGIN CERTIFICATE-----\n" \
"MIIFBjCCAu6gAwIBAgIRAMISMktwqbSRcdxA9+KFJjwwDQYJKoZIhvcNAQELBQAw\n" \
"TzELMAkGA1UEBhMCVVMxKTAnBgNVBAoTIEludGVybmV0IFNlY3VyaXR5IFJlc2Vh\n" \
"cmNoIEdyb3VwMRUwEwYDVQQDEwxJU1JHIFJvb3QgWDEwHhcNMjQwMzEzMDAwMDAw\n" \
"WhcNMjcwMzEyMjM1OTU5WjAzMQswCQYDVQQGEwJVUzEWMBQGA1UEChMNTGV0J3Mg\n" \
"RW5jcnlwdDEMMAoGA1UEAxMDUjEyMIIBIjANBgkqhkiG9w0BAQEFAAOCAQ8AMIIB\n" \
"CgKCAQEA2pgodK2+lP474B7i5Ut1qywSf+2nAzJ+Npfs6DGPpRONC5kuHs0BUT1M\n" \
"5ShuCVUxqqUiXXL0LQfCTUA83wEjuXg39RplMjTmhnGdBO+ECFu9AhqZ66YBAJpz\n" \
"kG2Pogeg0JfT2kVhgTU9FPnEwF9q3AuWGrCf4yrqvSrWmMebcas7dA8827JgvlpL\n" \
"Thjp2ypzXIlhZZ7+7Tymy05v5J75AEaz/xlNKmOzjmbGGIVwx1Blbzt05UiDDwhY\n" \
"XS0jnV6j/ujbAKHS9OMZTfLuevYnnuXNnC2i8n+cF63vEzc50bTILEHWhsDp7CH4\n" \
"WRt/uTp8n1wBnWIEwii9Cq08yhDsGwIDAQABo4H4MIH1MA4GA1UdDwEB/wQEAwIB\n" \
"hjAdBgNVHSUEFjAUBggrBgEFBQcDAgYIKwYBBQUHAwEwEgYDVR0TAQH/BAgwBgEB\n" \
"/wIBADAdBgNVHQ4EFgQUALUp8i2ObzHom0yteD763OkM0dIwHwYDVR0jBBgwFoAU\n" \
"ebRZ5nu25eQBc4AIiMgaWPbpm24wMgYIKwYBBQUHAQEEJjAkMCIGCCsGAQUFBzAC\n" \
"hhZodHRwOi8veDEuaS5sZW5jci5vcmcvMBMGA1UdIAQMMAowCAYGZ4EMAQIBMCcG\n" \
"A1UdHwQgMB4wHKAaoBiGFmh0dHA6Ly94MS5jLmxlbmNyLm9yZy8wDQYJKoZIhvcN\n" \
"AQELBQADggIBAI910AnPanZIZTKS3rVEyIV29BWEjAK/duuz8eL5boSoVpHhkkv3\n" \
"4eoAeEiPdZLj5EZ7G2ArIK+gzhTlRQ1q4FKGpPPaFBSpqV/xbUb5UlAXQOnkHn3m\n" \
"FVj+qYv87/WeY+Bm4sN3Ox8BhyaU7UAQ3LeZ7N1X01xxQe4wIAAE3JVLUCiHmZL+\n" \
"qoCUtgYIFPgcg350QMUIWgxPXNGEncT921ne7nluI02V8pLUmClqXOsCwULw+PVO\n" \
"ZCB7qOMxxMBoCUeL2Ll4oMpOSr5pJCpLN3tRA2s6P1KLs9TSrVhOk+7LX28NMUlI\n" \
"usQ/nxLJID0RhAeFtPjyOCOscQBA53+NRjSCak7P4A5jX7ppmkcJECL+S0i3kXVU\n" \
"y5Me5BbrU8973jZNv/ax6+ZK6TM8jWmimL6of6OrX7ZU6E2WqazzsFrLG3o2kySb\n" \
"zlhSgJ81Cl4tv3SbYiYXnJExKQvzf83DYotox3f0fwv7xln1A2ZLplCb0O+l/AK0\n" \
"YE0DS2FPxSAHi0iwMfW2nNHJrXcY3LLHD77gRgje4Eveubi2xxa+Nmk/hmhLdIET\n" \
"iVDFanoCrMVIpQ59XWHkzdFmoHXHBV7oibVjGSO7ULSQ7MJ1Nz51phuDJSgAIU7A\n" \
"0zrLnOrAj/dfrlEWRhCvAgbuwLZX1A2sjNjXoPOHbsPiy+lO1KF8/XY7\n" \
"-----END CERTIFICATE-----"
#define TX_TOPIC "device1/tx"
#define RX_TOPIC "device1/rx"

// Called when we connected to the MQTT server
void my_mqtt_on_connect(struct mg_connection *c, int code) {
  struct mg_mqtt_opts opts;
  memset(&opts, 0, sizeof(opts));
  opts.qos = 1;
  opts.topic = mg_str(RX_TOPIC);  // Subscribe to the RX topic
  mg_mqtt_sub(c, &opts);
  MG_DEBUG(("%lu code %d. Subscribing to [%.*s]", c->id, code, opts.topic.len,
            opts.topic.buf));
}

// This function gets called for every received MQTT message
void my_mqtt_on_message(struct mg_connection *c, struct mg_str topic,
                          struct mg_str data) {
  printf("\n%s\n\r",data.buf);
  strcpy(mystr, data.buf);
  rxflag = 1;
}

void my_mqtt_sendmessage(char *mensaje)
{
	if (g_mqtt_conn != NULL)
	{
	    struct mg_mqtt_opts opts;        // Publish MQTT response
	    memset(&opts, 0, sizeof(opts));  // to the TX topic
	    opts.topic = mg_str(TX_TOPIC);
	    opts.message = mg_str(mensaje);
	    mg_mqtt_pub(g_mqtt_conn, &opts);
	}
}

// This function is called on every control MQTT message
void my_mqtt_on_cmd(struct mg_connection *c, struct mg_mqtt_message *mm) {
  MG_DEBUG(("%lu cmd %d qos %d", c->id, mm->cmd, mm->qos));
}

// This function creates MQTT server connection
struct mg_connection *my_mqtt_connect(mg_event_handler_t fn) {
  const char *url = WIZARD_MQTT_URL;
  struct mg_connection *c;
  struct mg_mqtt_opts opts;
  memset(&opts, 0, sizeof(opts));
  opts.clean = true;
  struct mg_str usuario;
  usuario.buf = "Usuario";
  usuario.len = strlen(usuario.buf);
  struct mg_str contrasena;
  contrasena.buf = "Admin123";
  contrasena.len = strlen(contrasena.buf);
  struct mg_str iden;
  iden.buf = "STM32_cliente";
  iden.len = strlen(iden.buf);
  opts.user = usuario;
  opts.pass = contrasena;
  opts.client_id = iden;
  opts.keepalive = 6000;
  if ((c = mg_mqtt_connect(&g_mgr, url, &opts, fn, NULL)) != NULL) {
    MG_DEBUG(("%lu TLS enabled: %s", c->id, c->is_tls ? "yes" : "no"));
    if (c->is_tls) {
      struct mg_tls_opts tls_opts;
      memset(&tls_opts, 0, sizeof(tls_opts));
      tls_opts.ca = mg_str(TLS_CA);
      tls_opts.name = mg_url_host(url);
      mg_tls_init(c, &tls_opts);
    }
  }
  return c;
}

/* USER CODE END 0 */

/**
  * @brief  The application entry point.
  * @retval int
  */
int main(void)
{

  /* MCU Configuration--------------------------------------------------------*/

  /* Reset of all peripherals, Initializes the Flash interface and the Systick. */
  HAL_Init();

  /* Configure the system clock */
  SystemClock_Config();

  /* Initialize all configured peripherals */
  MX_GPIO_Init();
  MX_ETH_Init();
  MX_RNG_Init();
  MX_USART3_UART_Init();
  MX_MBEDTLS_Init();
  MX_TIM2_Init();
  MX_SPI1_Init();
  MX_TIM1_Init();
  MX_RTC_Init();
  MX_TIM9_Init();
  /* USER CODE BEGIN 2 */
  HAL_TIM_PWM_Start(&htim1, TIM_CHANNEL_2);
  HAL_TIM_PWM_Start(&htim9, TIM_CHANNEL_2);
  int servo_signal = 38;
  HAL_TIM_Base_Start_IT(&htim2);
  mongoose_init();

  SH1106_Init();
  SH1106_Flush();
  SH1106_SetXDir(LCD_INVERT_ON);
  SH1106_SetYDir(LCD_INVERT_ON);

  GPIO_PinState lecturas[8];
  GPIO_PinState lect_prev[8];
  int espacios_temp = 0;
  int espacios_lib = 0;
  int espacios_camb = 0;

  char display[20];

  struct mongoose_mqtt_handlers mqtt_handlers = {
	  my_mqtt_connect, my_mqtt_on_connect,
	  my_mqtt_on_message, my_mqtt_on_cmd,
  };
  mongoose_set_mqtt_handlers(&mqtt_handlers);

  SH1106_Fill(0);
  LCD_PutStr(XCOORD,YCOORD,"Espacios:",&Font7x10);
  sprintf(display, "%d", 8);
  LCD_PutStr(XCOORD+XOFFSET,YCOORD+YOFFSET,display,&Font7x10);
  SH1106_Flush();
  servo_signal = (int) (0*slope+yint);
  TIM1->CCR2 = servo_signal;
  int flag2 = 1;
  int flag1 = 0;

  /* USER CODE END 2 */

  /* Infinite loop */
  /* USER CODE BEGIN WHILE */
  while (1)
  {
    /* USER CODE END WHILE */

    /* USER CODE BEGIN 3 */
	  if((mg_now()>170000000) && flag2)
	  {
		  flag2 = 0;
		  updateTime();
	  }
	  mongoose_poll();
	  if(flag1 == 2)
	  {
		  if(rxflag)
			  decodificar_msg();
		  espacios_temp = 0;

		  //Espacios activos
		  for(int i=0; i<8; i++)
		  {
			  if(espacios[i] != RESERVADO)
			  {
				  lecturas[i] = HAL_GPIO_ReadPin(entradas[i].port,entradas[i].pin);
				  if(lecturas[i] == GPIO_PIN_SET)
				  {
					  espacio_ocupado(i);
					  espacios[i] = OCUPADO;
					  espacios_temp++;
				  }
				  else
				  {
					  espacio_libre(i);
					  espacios[i] = LIBRE;
				  }
				  if (lecturas[i] != lect_prev[i])
				  {
					  preparar_msg(i, espacios[i]);
					  my_mqtt_sendmessage(mensajito);
				  }
				  lect_prev[i] = lecturas[i];
			  }
			  else
			  {
				  espacio_reservado(i);
			  }
		  }
		  //Espacios pasivos
		  for(int i = 8; i<16; i++)
		  {
			  espacio_pasivo(i);
			  if(espacios[i] == RESERVADO)
			  {
				  espacios_temp++;
			  }
		  }

		  num_espacios = espacios_temp;
		  espacios_lib = 16 - num_espacios;
		  if(espacios_lib != espacios_camb)
		  {
			  SH1106_Fill(0);
			  LCD_PutStr(XCOORD,YCOORD,"Espacios:",&Font7x10);
			  sprintf(display, "%d", espacios_lib);
			  LCD_PutStr(XCOORD+XOFFSET,YCOORD+YOFFSET,display,&Font7x10);
			  SH1106_Flush();
		  }
		  espacios_camb = espacios_lib;
		  if((HAL_GPIO_ReadPin(INENTER_GPIO_Port, INENTER_Pin) == GPIO_PIN_SET) && espacios_lib > 0)
		  {
			  abrirPluma(TIM9, 1);
		  }
		  if(HAL_GPIO_ReadPin(INEXIT_GPIO_Port, INEXIT_Pin) == GPIO_PIN_SET)
		  {
			  abrirPluma(TIM1, 0);
		  }
		  HAL_GPIO_WritePin(LEDRED_GPIO_Port, LEDRED_Pin,GPIO_PIN_RESET);
	  }
	  else if(flag1 == 1)
	  {
		  for(int i=0; i<16; i++)
		  {
			  preparar_msg(i, espacios[i]);
			  my_mqtt_sendmessage(mensajito);
		  }
		  flag1 = 2;
	  }
	  else
	  {
		  HAL_GPIO_WritePin(LEDRED_GPIO_Port, LEDRED_Pin,GPIO_PIN_SET);
		  flag1 = (HAL_GPIO_ReadPin(COMENZAR_GPIO_Port, COMENZAR_Pin) == GPIO_PIN_SET);
		  for(int i=0; i<16; i++)
		  {
			  if(i<8)
			  {
				  HAL_GPIO_WritePin(leds_azules[i].port, leds_azules[i].pin, GPIO_PIN_SET);
			  }
			  else
			  {
				  HAL_GPIO_WritePin(leds_azules2[i-8].port, leds_azules2[i-8].pin, GPIO_PIN_SET);
			  }
		  }
	  }
  }
  /* USER CODE END 3 */
}

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
/* USER CODE BEGIN 4 */
void HAL_TIM_PeriodElapsedCallback(TIM_HandleTypeDef *htim)
{
	contadorentrada++;
	contadorsalida++;
	if(contadorentrada>3000)
	{
		TIM9->CCR2 = servoenterdefault;
	}
	if(contadorsalida>3000)
	{
		TIM1->CCR2 = servoexitdefault;
	}
}
//Espacios activos
void espacio_ocupado(int num)
{
	HAL_GPIO_WritePin(leds_rojos[num].port,leds_rojos[num].pin,LEDON);
	HAL_GPIO_WritePin(leds_verdes[num].port,leds_verdes[num].pin,LEDOFF);
	HAL_GPIO_WritePin(leds_azules[num].port,leds_azules[num].pin,LEDOFF);
}
void espacio_libre(int num)
{
	HAL_GPIO_WritePin(leds_rojos[num].port,leds_rojos[num].pin,LEDOFF);
	HAL_GPIO_WritePin(leds_verdes[num].port,leds_verdes[num].pin,LEDON);
	HAL_GPIO_WritePin(leds_azules[num].port,leds_azules[num].pin,LEDOFF);
}
void espacio_reservado(int num)
{
	HAL_GPIO_WritePin(leds_rojos[num].port,leds_rojos[num].pin,LEDOFF);
	HAL_GPIO_WritePin(leds_verdes[num].port,leds_verdes[num].pin,LEDOFF);
	HAL_GPIO_WritePin(leds_azules[num].port,leds_azules[num].pin,LEDON);
}

//Espacios pasivos
void espacio_pasivo(int num)
{
	if(espacios[num] == RESERVADO)
	{
		HAL_GPIO_WritePin(leds_azules2[num-8].port,leds_azules2[num-8].pin,LEDON);
		HAL_GPIO_WritePin(leds_verdes2[num-8].port,leds_verdes2[num-8].pin,LEDOFF);
	}
	else
	{
		HAL_GPIO_WritePin(leds_azules2[num-8].port,leds_azules2[num-8].pin,LEDOFF);
		HAL_GPIO_WritePin(leds_verdes2[num-8].port,leds_verdes2[num-8].pin,LEDON);
	}
}
void preparar_msg(int id, int estado)
{
	//codificar
	int codigo;
	switch(id)
	{
		case 0:
			codigo = 1;
		break;
	  	case 1:
	  		codigo = 5;
		break;
	  	case 2:
	  		codigo = 4;
		break;
	  	case 3:
	  		codigo = 8;
		break;
	  	case 4:
	  		codigo = 10;
		break;
	  	case 5:
	  		codigo = 14;
		break;
	  	case 6:
	  		codigo = 15;
		break;
	  	case 7:
	  		codigo = 12;
		break;
	  	case 8:
	  		codigo = 2;
		break;
	  	case 9:
	  		codigo = 6;
		break;
	  	case 10:
	  		codigo = 3;
		break;
	  	case 11:
	  		codigo = 7;
		break;
	  	case 12:
	  		codigo = 9;
		break;
	  	case 13:
	  		codigo = 13;
		break;
	  	case 14:
	  		codigo = 11;
		break;
	  	case 15:
	  		codigo = 16;
		break;
	}

	//init
	char str[20];
	mensajito[0] = '\0';

	//parkingId
	strcat(mensajito, "{\"parkingId\":\"");
	if(codigo<9)
		sprintf(str, "%d", 1);
	else
		sprintf(str,"%d", 2);
	strcat(mensajito, str);

	//spotId
	strcat(mensajito, "\",\"spotId\":");
	if(codigo<9)
		sprintf(str, "%d", codigo);
	else
		sprintf(str, "%d", codigo-8);
	strcat(mensajito, str);

	//spotNumber
	strcat(mensajito, ",\"spotNumber\":\"");
	if(codigo<9)
		strcat(mensajito, ids[codigo-1]);
	else
		strcat(mensajito, ids[codigo-9]);

	//estado
	strcat(mensajito, "\",\"estado\":\"");
	strcat(mensajito, estados[estado]);

	//timestamp
	sprintf(str,"\",\"timestamp\":%lld}",(long long)time(NULL)*1000);
	strcat(mensajito, str);

}
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

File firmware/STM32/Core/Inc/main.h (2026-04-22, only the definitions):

#define AZU1_4_Pin GPIO_PIN_2
#define AZU1_4_GPIO_Port GPIOE
#define VER2_4_Pin GPIO_PIN_3
#define VER2_4_GPIO_Port GPIOE
#define AZU2_4_Pin GPIO_PIN_4
#define AZU2_4_GPIO_Port GPIOE
#define COMENZAR_Pin GPIO_PIN_13
#define COMENZAR_GPIO_Port GPIOC
#define VER1_2_Pin GPIO_PIN_0
#define VER1_2_GPIO_Port GPIOF
#define VER2_2_Pin GPIO_PIN_1
#define VER2_2_GPIO_Port GPIOF
#define AZU2_2_Pin GPIO_PIN_2
#define AZU2_2_GPIO_Port GPIOF
#define ROJ1_3_Pin GPIO_PIN_3
#define ROJ1_3_GPIO_Port GPIOF
#define VER1_8_Pin GPIO_PIN_4
#define VER1_8_GPIO_Port GPIOF
#define ROJ1_6_Pin GPIO_PIN_6
#define ROJ1_6_GPIO_Port GPIOF
#define ROJ1_7_Pin GPIO_PIN_7
#define ROJ1_7_GPIO_Port GPIOF
#define AZU1_2_Pin GPIO_PIN_8
#define AZU1_2_GPIO_Port GPIOF
#define VER1_5_Pin GPIO_PIN_10
#define VER1_5_GPIO_Port GPIOF
#define AZU2_8_Pin GPIO_PIN_0
#define AZU2_8_GPIO_Port GPIOC
#define VER2_8_Pin GPIO_PIN_3
#define VER2_8_GPIO_Port GPIOC
#define INENTER_Pin GPIO_PIN_4
#define INENTER_GPIO_Port GPIOA
#define INEXIT_Pin GPIO_PIN_0
#define INEXIT_GPIO_Port GPIOB
#define ROJ1_8_Pin GPIO_PIN_1
#define ROJ1_8_GPIO_Port GPIOB
#define VER2_1_Pin GPIO_PIN_14
#define VER2_1_GPIO_Port GPIOF
#define ROJ1_1_Pin GPIO_PIN_15
#define ROJ1_1_GPIO_Port GPIOF
#define ROJ1_2_Pin GPIO_PIN_0
#define ROJ1_2_GPIO_Port GPIOG
#define VER2_5_Pin GPIO_PIN_7
#define VER2_5_GPIO_Port GPIOE
#define VER2_7_Pin GPIO_PIN_8
#define VER2_7_GPIO_Port GPIOE
#define VER1_1_Pin GPIO_PIN_9
#define VER1_1_GPIO_Port GPIOE
#define AZU2_5_Pin GPIO_PIN_10
#define AZU2_5_GPIO_Port GPIOE
#define AZU1_3_Pin GPIO_PIN_12
#define AZU1_3_GPIO_Port GPIOE
#define AZU1_1_Pin GPIO_PIN_13
#define AZU1_1_GPIO_Port GPIOE
#define AZU2_3_Pin GPIO_PIN_14
#define AZU2_3_GPIO_Port GPIOE
#define AZU2_1_Pin GPIO_PIN_15
#define AZU2_1_GPIO_Port GPIOE
#define Reset_Pin GPIO_PIN_10
#define Reset_GPIO_Port GPIOB
#define IN5_Pin GPIO_PIN_11
#define IN5_GPIO_Port GPIOB
#define IN8_Pin GPIO_PIN_12
#define IN8_GPIO_Port GPIOB
#define LEDRED_Pin GPIO_PIN_14
#define LEDRED_GPIO_Port GPIOB
#define ROJ1_5_Pin GPIO_PIN_15
#define ROJ1_5_GPIO_Port GPIOB
#define AZU1_5_Pin GPIO_PIN_11
#define AZU1_5_GPIO_Port GPIOD
#define AZU2_7_Pin GPIO_PIN_12
#define AZU2_7_GPIO_Port GPIOD
#define AZU1_8_Pin GPIO_PIN_13
#define AZU1_8_GPIO_Port GPIOD
#define VER1_3_Pin GPIO_PIN_14
#define VER1_3_GPIO_Port GPIOD
#define VER2_3_Pin GPIO_PIN_15
#define VER2_3_GPIO_Port GPIOD
#define AZU1_6_Pin GPIO_PIN_2
#define AZU1_6_GPIO_Port GPIOG
#define AZU2_6_Pin GPIO_PIN_3
#define AZU2_6_GPIO_Port GPIOG
#define IN3_Pin GPIO_PIN_5
#define IN3_GPIO_Port GPIOG
#define IN1_Pin GPIO_PIN_6
#define IN1_GPIO_Port GPIOG
#define CS_Pin GPIO_PIN_8
#define CS_GPIO_Port GPIOA
#define IN6_Pin GPIO_PIN_10
#define IN6_GPIO_Port GPIOC
#define IN7_Pin GPIO_PIN_12
#define IN7_GPIO_Port GPIOC
#define ROJ1_4_Pin GPIO_PIN_0
#define ROJ1_4_GPIO_Port GPIOD
#define AZU1_7_Pin GPIO_PIN_3
#define AZU1_7_GPIO_Port GPIOD
#define VER1_7_Pin GPIO_PIN_4
#define VER1_7_GPIO_Port GPIOD
#define VER1_6_Pin GPIO_PIN_5
#define VER1_6_GPIO_Port GPIOD
#define VER2_6_Pin GPIO_PIN_6
#define VER2_6_GPIO_Port GPIOD
#define VER1_4_Pin GPIO_PIN_7
#define VER1_4_GPIO_Port GPIOD
#define IN2_Pin GPIO_PIN_9
#define IN2_GPIO_Port GPIOG
#define DC_Pin GPIO_PIN_4
#define DC_GPIO_Port GPIOB
#define IN4_Pin GPIO_PIN_1
#define IN4_GPIO_Port GPIOE

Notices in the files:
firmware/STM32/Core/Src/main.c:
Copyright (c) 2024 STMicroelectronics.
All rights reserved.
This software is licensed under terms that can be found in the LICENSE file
